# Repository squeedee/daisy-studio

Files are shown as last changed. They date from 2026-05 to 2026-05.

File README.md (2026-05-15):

# Daisy Studio - [Website](https://squeedee.github.io/daisy-studio/)

| Front | Back |
|---|---|
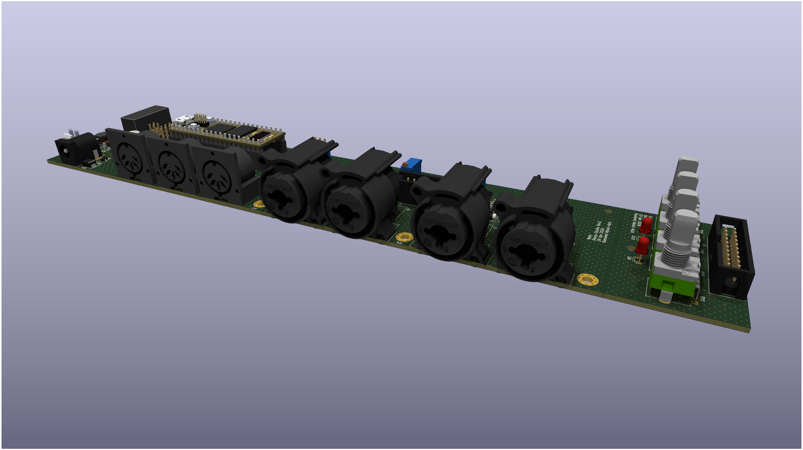
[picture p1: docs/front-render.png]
Front render
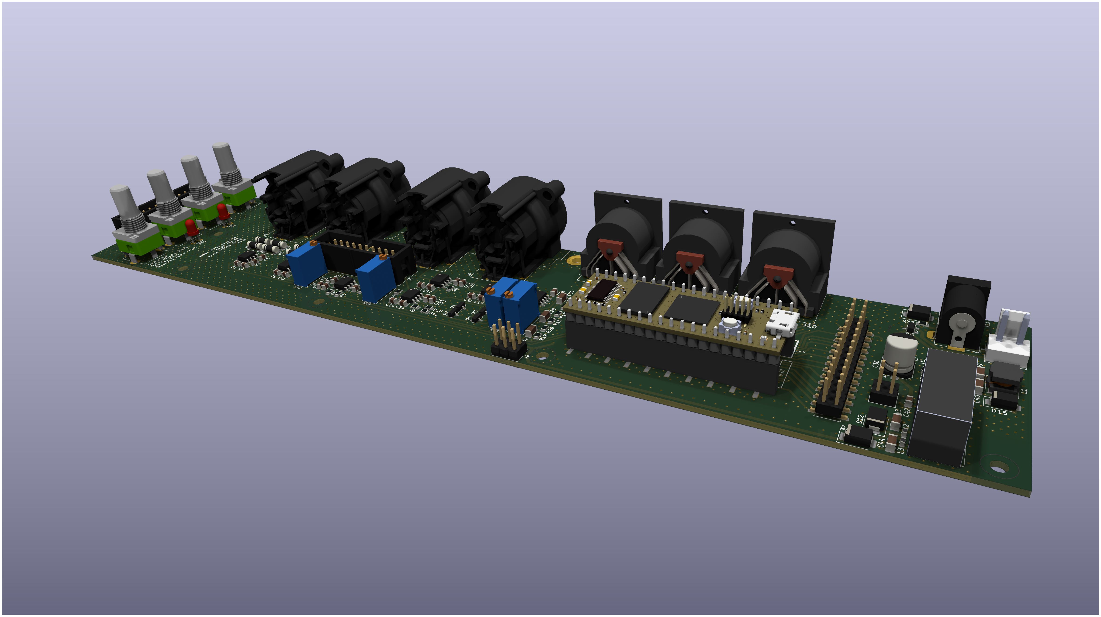
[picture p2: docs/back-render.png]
Back render
|  |  |

A development board for the [Electrosmith Daisy Seed](https://www.electro-smith.com/daisy/daisy)
DSP module, providing professional studio-grade balanced line input and output.

Schematic PDF: [docs/Daisy Studio Rev2.pdf](docs/Daisy%20Studio%20Rev2.pdf)

THD measurement report (Board 1, loopback, post-F9 retrim — ≤ −88 dB / ≤ 0.004 % @ 1 kHz):
[docs/Daisy THD Meter.pdf](docs/Daisy%20THD%20Meter.pdf)

The board is designed as a **flexible development board** to prototype designs
for:

* synthesizers, desktop, rackmount or with keybeds.
* effects modules, desktop or rackmount.

The main PCB carries all active circuitry and connects to a passive **daughterboard**
that holds the user-facing controls (level pots, clip LEDs).

The designer can replace the daughterboard with controls connected however they desire.

## Features

- **Balanced audio I/O** using THAT Corporation ICs:
    - 2× THAT1246 balanced line receivers (stereo input).
    - 2× THAT1646 balanced line drivers (stereo output).
- **OPA1656 gain stages** on input and output, calibrated for +24 dBu
  peak studio levels.
- **BJT input clamp** with an LM2903 comparator clip indicator —
  protects the Seed's PCM3060 ADC against overdrive and provides user's with professional gain stage control.
- **Neutrik combo jacks** (NCJ6FA-H-0) on all four audio connectors —
  accept both XLR and 1/4" TRS
- **MIDI** in, out, and thru via 5-pin DIN connectors with optoisolated input.
- **Micro SD card** slot.
- **Daughterboard header** (2×10 IDC, ribbon or stack-mount) for
  user-facing gain controls and input clip LEDs.
- **Seed GPIO breakout** header (2×14) for user expansion
- **Analog power** header (2x3) provides +-12v rails for additional analog circuits.
- **Panel power switch** header (JST VH) — ships with a shunt by default,
  swap for a switch harness when wanted.
- **Isolated Chassis Ground** jumper JP1 allows chassis ground to be kept separate 
  from signal grounds. Mounting posts (H1, H4 and H7) share the chassis ground/shield 
  of the Neutrik connectors.

## Circuit Function

### Audio Input

```
Balanced in → THAT1246 → OPA1656 (fixed gain) → daughterboard pot
                                                       ↓
   Daisy Seed ← C_aa anti-alias ← BJT clamp ← R_out (3.3 kΩ) ←
```

The **THAT1246** balanced receiver converts the differential XLR input
to single-ended at −6 dB, keeping +24 dBu peaks within the ±10 V output
swing of the ±12 V rails. Its **Sense pin (5)** is brought back as a
separate trace to the OPA1656 inverting node — Kelvin-connected past
the input resistor — so the THAT1246's internal feedback amp absorbs
any voltage drop across `R_in`, eliminating it as a gain-error term.

The **OPA1656** runs as an inverting amplifier at a **fixed gain of
1.2×** (R_fb = 12 kΩ, R_in = 10 kΩ). At +24 dBu peak input the op-amp
output reaches ±10.45 V, ~550 mV from the ±11 V clip rails. Fixed gain
(rather than a pot in the feedback path) keeps loop phase margin
constant across user level adjustments, and the high-impedance summing
junction stays entirely on the main PCB.

User level is set by a **10 kΩ log pot on the daughterboard**, wired
as a passive three-terminal voltage divider downstream of the op-amp.
Both header legs are low-impedance: the op-amp drives the CW terminal,
and the pot wiper returns to the main PCB into `R_out` (3.3 kΩ) which
caps fault current into the clamp under pathological overdrive.

The **BJT clamp** is the design's centrepiece. A complementary pair
(2N3906 PNP + 2N3904 NPN) per channel clamps the Seed input pin against
±1.565 V references derived from the ±12 V rails by 10 kΩ / 1.5 kΩ
dividers and held stiff at audio frequencies by 47 µF MLCCs. The
transistors' β ≈ 200 means only Ic / β flows through the reference
divider base connection, so the references stay nearly stationary even
under sustained overdrive — the "reference pumping" failure mode that
limits passive diode clamps. The sharp emitter-base knee (NF ≈ 1.24,
versus ~1.82 for diodes) lets the clean signal use the full ADC range
with no distortion. Simulations across five tolerance corners shows
worst-case codec voltage of 4.64 V under +24 dBu pathological overdrive
— 164 mV margin to the PCM3060's 4.8 V damage ceiling.

A **1 nF C0G capacitor** at the Seed input pin, after the clamp, forms
a single-pole LPF with `R_out` plus the pot wiper source impedance.
The corner stays between 27 kHz (pot mid) and 48 kHz (pot ends), well
above the audio band, attenuating wideband op-amp noise and out-of-band
content before it reaches the PCM3060's sigma-delta ADC.

A **clip indicator** uses an LM2903 comparator monitoring the Seed
input against an adjustable threshold. A trim pot on the daughterboard
(0 V to +1.565 V) sets the threshold; the open-collector output sinks
an LED current path against +12 V through a 1 kΩ limit on the main PCB.
At audio frequencies the LED flickers faster than the eye sees — a dim
glow at light clipping, bright at heavy. A single LM2903 covers both
channels.

### MIDI

Standard MIDI 1.0 — a 5 mA current loop at 31.25 kbaud on three
SDS-50J DIN-5 jacks (IN, OUT, THRU).

```
DIN-5 IN ── 220R × 2 ── 1N4148W ── H11L1SM (opto, Schmitt)
                                       ├── 270R pull-up to +3V3D
                                       ├── → MIDI_RX → Seed UART RX
                                       └── 33R × 2 → DIN-5 THRU

Seed UART TX ── MIDI_TX ── 33R + 10R ── DIN-5 OUT
```

The H11L1SM Schmitt-trigger optocoupler galvanically isolates the input
per the MIDI 1.0 electrical spec and presents clean UART edges to the
Seed. THRU buffers the same opto output through a second pair of 33 Ω
series resistors. OUT is driven directly from the Seed UART TX through
a 33 Ω + 10 Ω series pair.

### Audio Output

```
Seed audio → OPA1656 (gain ~9.1×, C_fb LPF) → daughterboard pot
                                                       ↓
        XLR ← SM4004 phantom clamps ← THAT1646 balanced driver ←
```

The Seed's PCM3060 outputs ~2 V p-p at digital full scale (~−1 dBu
single-ended, ~+5 dBu differential through the THAT1646 alone). An
OPA1656 inverting gain stage closes the ~20 dB gap to the +24 dBu
studio peak target. R_in is a fixed 2.2 kΩ; R_fb is **15 kΩ fixed in
series with a 10 kΩ multi-turn cermet trimmer** (e.g. Bourns
3296W-1-103). Mid-trim lands at gain ~9.1× (+23.7 dBu peak); the
25-turn trim resolves to ~0.5% of R_fb. The fixed floor prevents
accidental hard clipping if the wiper loses contact, and the ceiling
(R_fb ≤ 25 kΩ) stays below the OPA1656's onset of clipping.

A **100 pF C0G across R_fb** turns the gain stage into a single-pole
LPF with f_c ≈ 80 kHz at nominal trim. The Seed Rev 7's PCM3060 has
out-of-band delta-sigma noise that the codec's internal RC alone does
not adequately attenuate; the in-feedback-loop LPF handles this
without adding any series parts. C0G dielectric is required —
X5R/X7R have voltage-coefficient distortion that would intrude into
the audio band when the cap is in the feedback path. Sim shows
−0.27 dB at 20 kHz, −22 dB at 1 MHz.

User output level is a **10 kΩ log pot per channel on the
daughterboard**, voltage-divider-wired downstream of the op-amp. Two
separate pots (not ganged) let users pick their own taper or matching
strategy. The THAT1646's high-Z input means the op-amp sees a constant
10 kΩ load regardless of wiper position.

The **THAT1646** balanced driver converts the single-ended pot wiper
back to a differential XLR pair. Sense pins close the feedback loop at
the XLR connector for cross-coupled output impedance and immunity to
load imbalance.

**Phantom-power protection**: four SM4004 diodes per channel (two per
XLR pin) clamp the THAT1646 output to the ±12 V rails. If an XLR is
plugged into a phantom-enabled mic preamp, +48 V through the preamp's
6.8 kΩ feed produces ~5 mA per pin into the clamp — well within the
SM4004's 1 A rating.

**Rail protection** (phantom back-feed when the gear is powered off):
one SMBJ15CA bidirectional TVS on each ±12 V rail to AGND, placed near
the RS3-1212D output. Same part as the input over-voltage TVS for BOM
consolidation. Clamps when the rail magnitude exceeds ~16 V.

### Daughterboard Architecture

The main PCB commits to a **2×10 (20-pin) 2.54 mm pitch through-hole
footprint** for the daughterboard header. Daughterboard PCBs are
**fully passive**, populating only:

- 2× input level pots (10 kΩ log)
- 2× output level pots (10 kΩ log)
- 2× clip LEDs

No ICs, no power rails, and no high-impedance feedback nodes cross the
header — shorting any two daughterboard signals together cannot damage
the main PCB. The 18 needed signal pins fit in the 20-pin footprint
with two AGND pins at the bottom; AGND is interleaved on every audio
pair.

The same footprint supports two build modes:

- **Cable-mount**: a shrouded IDC header (e.g. Samtec
  TSS-110-01-G-D) on the main PCB, 20-way IDC ribbon to a matching
  socket, or a soldered header (lower profile) on the daughterboard.
  Cable length ≤ 150 mm comfortable.
- **Pins and Shielded pairs**: Alternatively pins and shielded wire pairs
  can run longer distances.
- **Stack-mount (default)**: Samtec flex-stacking posts; the daughterboard sits
  directly above the main PCB at a chosen height, no cable.

Pinout (canonical):

| Pin | Signal | Pin | Signal |
|----:|---|----:|---|
| 1 | AGND | 2 | AGND |
| 3 | IN_OPA_L | 4 | IN_OPA_R |
| 5 | IN_WIPER_L | 6 | IN_WIPER_R |
| 7 | AGND | 8 | AGND |
| 9 | OUT_OPA_L |  10 | OUT_OPA_R |
|  11 | OUT_WIPER_L  |  12 | OUT_WIPER_R  |
|  13 | AGND |  14 | AGND |
|  15 | CLIP_LED_A_L |  16 | CLIP_LED_A_R |
|  17 | CLIP_LED_K_L |  18 | CLIP_LED_K_R |
|  19 | AGND |  20 | AGND |

The moderate-Z `IN_WIPER_*` pair and the fast-edge `CLIP_LED_K_*` pair
(LM2903 open-collector) sit at opposite ends of the header to limit
capacitive crosstalk on a ribbon. User extensions that need active
circuitry use the GPIO breakout header instead.

### Seed GPIO Breakout

A **2×14 (28-pin) 2.54 mm vertical pin header** brings out every Seed
GPIO not committed to the on-board audio (ADC/DAC), MIDI (UART_RX/TX),
or USB (D+/D−, VBUS) — plus +5 V, +3V3D, and DGND for downstream
circuits. Pin-to-net assignment is slightly illogical, as they were selected
to minimise via count and trace crossings between the Seed and the
breakout.

Analog ±12 V rails are not on the breakout (or on the daughterboard
header); they distribute through the dedicated power header.

### Power

```
12 V barrel jack → SW1 (panel switch / shunt) → DMP3056L (rev-polarity)
                                                       ↓
                                              SMBJ15CA TVS (overvoltage)
                                                       ↓
                                                100 µF bulk → +12V_RAW
                                                       ├─→ TPS54302 → +5V
                                                       └─→ RS3-1212D → ±12V
```

A 12 V wall-wart feeds a 2.1 mm barrel jack. **SW1** — a JST B2P-VH
2-pin THT header in series after the jack — takes either a pre-crimped
shunt harness (default, bypasses the switch) or an external panel
switch harness (VHR-2N housing, SVH-21T-P1.1 contacts). Placing the
switch *before* reverse-polarity protection means rev-pol and TVS
clamping still function during a miswired wall-wart event regardless
of switch state.

Reverse polarity is blocked by a **DMP3056L-13** P-FET (VGS_max ±20 V,
RDS_on ~51 mΩ) — sized for the −12 V on the gate that this
configuration imposes when input is correct. An **SMBJ15CA**
bidirectional TVS clamps any over-voltage spike from a misbehaved
supply. A 100 µF / 25 V electrolytic provides bulk on +12V_RAW.

The **TPS54302 buck** (SOT-23-6) generates +5 V from +12V_RAW for the
Daisy Seed and the MIDI front-end. Feedback divider 100 kΩ / 13.3 kΩ
sets Vout ≈ 5.07 V; inductor L3 = 10 µH (Bourns SRN6045TA). Output
caps are 2× 22 µF / 25 V X7R 1206 (5× voltage derating). A dedicated
**10 µF / 25 V X7R 1206** input MLCC sits at the VIN pin to handle the
buck's pulsed input current at 500 kHz with low loop inductance — the
part the TPS54302 datasheet calls for. A defensive **SMAJ5.0A** TVS
clamps +5 V to GND near the Seed.

The **Recom RS3-1212D** isolated DC/DC (SIP-8, 3 W, regulated ±2%,
±125 mA per rail) generates the ±12 V analog rails. The output passes
through 2× BLM18PG121SN1 ferrite beads into the rest of the board.

Power budget (±12 V rails):

| Consumer | +12V mA | −12V mA |
|---|---:|---:|
| 2× THAT1246 (input receivers)  | 16.0 | 16.0 |
| 2× THAT1646 (output drivers) | 18.0 | 18.0 |
| 1× OPA1656 (input gain, dual)  | 7.8 | 7.8 |
| 1× OPA1656 (output gain, dual) | 7.8 | 7.8 |
| BJT clamp reference dividers | 2.1 | 2.1 |
| LM2903 quiescent | 0.5 | 0.5 |
| **Total** | **~52** | **~52** |

≈ 1.25 W output power against the RS3-1212D's 3 W rating — ~2.4×
headroom, defensive margin against component tolerance and operating
temperature; margin for user consumption on the power header will be
validated and provided as a spec (once the boards are tested)

**Grounding**: AGND and DGND meet near the Seed's pin 20 (AGND) in a two
layer connection between AGND and DGND isolated planes.

AGND and CHASSIS meet only at JP1 (a solder jumper on the underside of the board)
Users can isolate the chassis ground of the Neutrik connectors by cutting this
jumper. Chassis Ground connects to all three mounting holes left, center and right
of the Neutrik connectors.

## Project Structure

Designed in KiCad 8 with a hierarchical schematic:

- `daisy-studio.kicad_sch` — root sheet
- `audio_input.kicad_sch` — input section (THAT1246, OPA1656, BJT clamp, LM2903)
- `audio_output.kicad_sch` — output section (OPA1656, THAT1646, phantom protection)
- `daisy_seed.kicad_sch` — Seed module + MIDI front-end + GPIO breakout
- `power.kicad_sch` — power section (buck + isolated DC/DC + protection)
- `daughter.kicad_sch` — passive daughterboard (separate fab)
- `misc.kicad_sch` — daughterboard header and mounting parts for the main board.

LTspice simulations validating the input-stage clamp / signal path and
the output reconstruction LPF live under `sim/input/` and `sim/output/`.

## Status

Rev 2 — fab sent.

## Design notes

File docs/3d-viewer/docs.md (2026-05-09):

# Daisy Studio (Rev2b)

[[view:overview|Front View]] and [[view:back|Back View]]

Development board for the Electrosmith Daisy Seed that brings a slew of features

## Clean Power [[view:power|Power]]

* 5V for the Seed and your UX via the TPS54302 buck (U10).
* Clean **±12V dual** rails for the analog stages from an RS3-1212D isolated DC/DC.
* Overvoltage protection on every rail via SMBJ15CA TVS, which also capture backfeed from voltage sources on the outputs
  when power is not applied.
* Reverse-polarity protection with a DMP3056L-13 P-FET.
* Optional power switch header at SW1 (can be jumpered).

## Power Headers [[view:power-header|Power Headers]]

* 5V and 3.3V at J12.
* ±12V at J8

## Balanced Audio In [[view:audio-input|Balanced Input]]

- Studio level (+24 dBu peak), balanced input on Neutrik Combo Jacks (J4, J6) via THAT1246 differential receivers.
- Gain control and clip indicators for perfect gain staging.
- Clip-threshold trim (RV7, RV8) so the clip LED lights *before* the protection clamp engages.
- BJT clamp (2N3904 + 2N3906 pairs at Q1, Q4 / Q2, Q3) protects the Seed's PCM3060 ADC from overdrive — sharp transistor
  knee, no diode-clamp distortion bleeding into your signal.
- C0G anti-alias cap (C16, C24) on each Seed input pin attenuates out-of-band noise before the codec's sigma-delta ADC
  sees it.

## Balanced Audio Out [[view:audio-output|Balanced Output]]

- Studio level (+24 dBu peak) on Neutrik Combo Jacks (J1, J2) via THAT1646 line drivers.
- Per-channel volume pots on the daughterboard so each output trims independently.
- Output gain trimmed once at calibration with 25-turn cermet pots (RV2, RV4) on the OPA1656 gain stage (U3).
- Phantom-power-safe: SM4004 diode clamps (D1–D8) to the ±12V rails on every XLR pin.

## 5-Pin MIDI [[view:midi|MIDI]]

- IN (J10), OUT (J9), and THRU (J7) on DIN-5 jacks.
- Galvanically isolated input via the H11L1SM Schmitt-trigger optocoupler (U8) — clean UART edges to the Seed.
- Standard MIDI 1.0 electrical spec.

## Seed [[view:seed|Seed]]

- Socketed Daisy Seed Rev 7 at U9.
- Every Seed GPIO not committed to onboard audio, MIDI, or USB is on the **2×14 GPIO breakout** at J11, plus +5V, +3V3D
  and DGND for your circuits.
- MicroSD slot (J14, underside of board) wired to the Seed's SD interface.
- USB and audio I/O routed straight through, no muxing.

## Daughter Board [[view:daughter-header|Daughter Board]]

- **2×10 (20-pin) 0.1" header** at J3 — your daughterboard, your UX layout.
- Fully passive: input/output pots + clip LEDs only. No ICs cross the header.
- Stack-mount or IDC ribbon — pick whichever fits your enclosure.
- AGND interleaved on every audio pair, so shorting any two pins won't damage the main PCB.

---

<p style="color: var(--muted); font-size: 12px;">
Source: <code>daisy-studio.kicad_pcb</code> · GLB exported with
<code>kicad-cli pcb export glb</code> · Viewer:
<a href="https://modelviewer.dev/" target="_blank" rel="noopener">&lt;model-viewer&gt;</a>
</p>

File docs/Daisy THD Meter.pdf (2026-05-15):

## Daisy THD Meter Report

5/15/2026, 6:31:22 PM

SETTINGS

Mode | Loopback
Channel | R
Window | Coherent (no window)
Test frequency | 1007.8125 Hz (bin 86)
FFT size / fs | 4096 / 48 kHz (bin width 11.71875 Hz)
Drive amplitude | 1.0000

MEASUREMENT

Fundamental | -4.02 dBFS
THD | -89.01 dB (0.0035 %)
THD + N | -89.01 dB
Peak | -4.0 dBFShold -4.0
Noise floor | -124.79 dBFS
5/15/26, 6:31 PM | Daisy THD Meter
localhost:63342/daisy-studio/firmware/projects/thd-meter/thd-meter.html?_ijt=5og25p2hi8ko8jm5ajpe94mvsb&_ij_reload=RELOAD_ON_SAVE | 1/2

HARMONICS (DB BELOW FUNDAMENTAL)

Order | dB | Visual

2

nd | -95.3

3

rd | -91.4

4

th | -99.7

5

th | -99.6

6

th | -112.0

7

th | -118.3

8

th | -122.5

9

th | -116.2

THD HISTORY (SNAPSHOT)

NOTES

—

localhost:63342/daisy-studio/firmware/projects/thd-meter/thd-meter.html?_ijt=5og25p2hi8ko8jm5ajpe94mvsb&_ij_reload=RELOAD_ON_SAVE | 2/2

## Daisy THD Meter Report

5/15/2026, 6:31:36 PM

SETTINGS

Mode | Loopback
Channel | L
Window | Coherent (no window)
Test frequency | 1007.8125 Hz (bin 86)
FFT size / fs | 4096 / 48 kHz (bin width 11.71875 Hz)
Drive amplitude | 1.0000

MEASUREMENT

Fundamental | -3.51 dBFS
THD | -87.93 dB (0.0040 %)
THD + N | -87.93 dB
Peak | -3.5 dBFShold -3.5
Noise floor | -125.57 dBFS
localhost:63342/daisy-studio/firmware/projects/thd-meter/thd-meter.html?_ijt=5og25p2hi8ko8jm5ajpe94mvsb&_ij_reload=RELOAD_ON_SAVE | 1/2

HARMONICS (DB BELOW FUNDAMENTAL)

Order | dB | Visual

2

nd | -88.9

3

rd | -95.5

4

th | -113.0

5

th | -105.2

6

th | -128.0

7

th | -121.9

8

th | -117.5

9

th | -115.2

THD HISTORY (SNAPSHOT)

NOTES

—

localhost:63342/daisy-studio/firmware/projects/thd-meter/thd-meter.html?_ijt=5og25p2hi8ko8jm5ajpe94mvsb&_ij_reload=RELOAD_ON_SAVE | 2/2

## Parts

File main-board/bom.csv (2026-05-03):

Refs | Value | Footprint | Manufacturer | MPN | Mouser P/N | Datasheet | Link | Description
C1,C2,C5,C6,C10,C13,C14,C17,C19,C20,C23,C25,C26,C31,C35,C37,C42 | 100n | Capacitor_SMD:C_0805_2012Metric | Samsung Electro-Mechanics | CL21B104KBCNNNC | 187-CL21B104KBCNNNC | https://www.mouser.com/datasheet/2/585/MLCC-1837944.pdf | https://www.mouser.com/ProductDetail/Samsung-Electro-Mechanics/CL21B104KBCNNNC?qs=349EhDEZ59pEfpnm5yBEmQ%3D%3D | Unpolarized capacitor
C3,C4,C7,C11,C12,C18,C21,C28 | 10u | Capacitor_SMD:C_0805_2012Metric | Samsung Electro-Mechanics | CL21A106KAYNNNE | 187-CL21A106KAYNNNE | https://www.mouser.com/datasheet/2/585/MLCC-1837944.pdf | https://www.mouser.com/ProductDetail/Samsung-Electro-Mechanics/CL21A106KAYNNNE?qs=yOVawPpwOwmTXAd4dJtNjA%3D%3D | Unpolarized capacitor
C8,C15 | 100p C0G | Capacitor_SMD:C_0805_2012Metric | Yageo | CC0805JRNPO9BN101 | 603-CC805JRNPO9BN101 | ~ | https://www.mouser.com/ProductDetail/YAGEO/CC0805JRNPO9BN101?qs=AgBp2OyFlx%252BIBvbseB%252BJ9Q%3D%3D | Unpolarized capacitor
C9,C16,C22,C24 | 1n | Capacitor_SMD:C_0805_2012Metric | Samsung Electro-Mechanics | CL21B102KBCNNNC | 187-CL21B102KBCNNNC | ~ | https://www.mouser.com/ProductDetail/Samsung-Electro-Mechanics/CL21B102KBCNNNC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 | Unpolarized capacitor
C27,C29,C30,C32 | 47u | Capacitor_SMD:C_1206_3216Metric | Samsung Electro-Mechanics | CL31A476MQHNNNE | 187-CL31A476MQHNNNE | ~ | https://www.mouser.com/ProductDetail/Samsung-Electro-Mechanics/CL31A476MQHNNNE?qs=349EhDEZ59oTPuXhtXd6IQ%3D%3D | Unpolarized capacitor
C33,C34 | 1n C0G | Capacitor_SMD:C_0603_1608Metric | Yageo | CC0603JRNPO8BN102 | 603-CC603JRNPO8BN102 | ~ | https://www.mouser.com/ProductDetail/YAGEO/CC0603JRNPO8BN102?qs=AgBp2OyFlx%2F%252ByYeYqr8Gwg%3D%3D | Unpolarized capacitor
C36 | 100u 25V | Capacitor_SMD:CP_Elec_6.3x7.7 | Panasonic | EEE-FK1E101XP | 667-EEE-FK1E101XP | https://industrial.panasonic.com/cdbs/www-data/pdf/RDE0000/ABA0000C1181.pdf | https://www.mouser.com/ProductDetail/Panasonic/EEE-FK1E101XP?qs=qE6bgDGEOCsW6NVslB4juQ%3D%3D | Polarized capacitor
C38 | 75pF | Capacitor_SMD:C_0805_2012Metric | Yageo | CC0805JRNPO9BN750 | 603-CC805JRNPO9BN750 | https://www.mouser.com/datasheet/3/508/1/upy-np0x7r_mv_100-to-630v.pdf | https://www.mouser.com/ProductDetail/YAGEO/CC0805JRNPO9BN750?qs=57cj7OiSijnuUmSjyzaxjQ%3D%3D | Unpolarized capacitor
C39 | 10u 25V | Capacitor_SMD:C_1206_3216Metric | Samsung Electro-Mechanics | CL31A106KAHNNNE | 187-CL31A106KAHNNNE | ~ | https://www.mouser.com/ProductDetail/Samsung-Electro-Mechanics/CL31A106KAHNNNE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 | Unpolarized capacitor
C40,C41,C43,C44 | 22u 25V | Capacitor_SMD:C_1206_3216Metric | Samsung Electro-Mechanics | CL31A226MAHNNNE | 187-CL31A226MAHNNNE | ~ | https://www.mouser.com/ProductDetail/Samsung-Electro-Mechanics/CL31A226MAHNNNE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 | Unpolarized capacitor
D1-D8 | SM4004 | Diode_SMD:D_MELF | Rectron | SM4004-W | 583-SM4004 | http://cdn-reichelt.de/documents/datenblatt/A400/SMD1N400%23DIO.pdf | https://www.mouser.com/ProductDetail/Rectron/SM4004-W?qs=Iw9Ubr57Px1JditZNV5Q2Q%3D%3D | 400V 1A General Purpose Rectifier Diode, MELF
D9,D10 | LED | LED_THT:LED_D3.0mm | Kingbright | WP710A10ID | 604-WP710A10ID | ~ | https://www.mouser.com/ProductDetail/Kingbright/WP710A10ID?qs=wRBQ8ZgBZ98VyHeNIlWGkQ%3D%3D | Light emitting diode
D11 | 1N4148WS | Diode_SMD:D_SOD-323 | Diodes Incorporated | 1N4148WS-7-F | 621-1N4148WS-F | https://www.vishay.com/docs/85751/1n4148ws.pdf | https://www.mouser.com/ProductDetail/Diodes-Incorporated/1N4148WS-7-F?qs=4drIV0IxA0r8aNy7%2Fu4kVw%3D%3D | 75V 0.15A Fast switching Diode, SOD-323
D12-D14 | SMBJ15CA | Diode_SMD:D_SMB | Diodes Incorporated | SMBJ15CA-13-F | 621-SMBJ15CA-13-F | ~ | https://www.mouser.com/ProductDetail/Diodes-Incorporated/SMBJ15CA-13-F?qs=gaDBXWSqsDDjKf8DgzD9yw%3D%3D | Bidirectional transient-voltage-suppression diode
D15 | SMAJ5.0A | Diode_SMD:D_SMA | Diodes Incorporated | SMAJ5.0A-13-F | 621-SMAJ5.0A-13-F | https://www.littelfuse.com/media?itemid=75e32973-b177-4ee3-a0ff-cedaf1abdb93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 | https://www.mouser.com/ProductDetail/Diodes-Incorporated/SMAJ5.0A-13-F?qs=gaDBXWSqsDCr%2F5d1gQdliw%3D%3D | 400W unidirectional Transient Voltage Suppressor, 5.0Vr, SMA(DO-214AC)
J1,J2,J4,J6 | NCJ6FA-H-0 | Connector_Audio:Jack_XLR-6.35mm_Neutrik_NCJ6FA-H-0_Horizontal | Neutrik | NCJ6FA-H-0 | 568-NCJ6FA-H-0 | https://www.neutrik.com/en/product/ncj6fa-h-0 | https://www.mouser.com/ProductDetail/Neutrik/NCJ6FA-H-0?qs=aEaV1LakhLaCrLXco%252BtEjw%3D%3D | Combo A series, 3 pole XLR female receptacle with 6.35mm (1/4in) stereo jack, horizontal PCB mount, retention spring
J3,J5 | Conn_02x10_Odd_Even | Connector_IDC:IDC-Header_2x10_P2.54mm_Vertical | Preci-dip | 892-70-020-10-001101 | 437-8927002010001101 | ~ | https://www.mouser.com/ProductDetail/Preci-dip/892-70-020-10-001101?qs=jrVTBkKbt4YjW5Ssdpp6%252BA%3D%3D | Generic connector, double row, 02x10, odd/even pin numbering scheme (row 1 odd numbers, row 2 even numbers), script generated (kicad-library-utils/schlib/autogen/connector/)
J7,J9,J10 | SDS-50J | daisy-studio:SDS50J | Same Sky | SDS-50J | 490-SDS-50J | https://www.mouser.com/datasheet/3/6118/1/sds-j.pdf | https://www.mouser.com/ProductDetail/Same-Sky/SDS-50J?qs=WyjlAZoYn50GAH9uA%252BxiOw%3D%3D | 5 Pin, Right-Angle Receptacle, 180
J8 | Conn_02x03 | Connector_PinHeader_2.54mm:PinHeader_2x03_P2.54mm_Vertical | Wurth Elektronik | 61300621121 | 710-61300621121 | https://www.we-online.com/components/products/datasheet/61300621121.pdf | https://www.mouser.com/ProductDetail/Wurth-Elektronik/61300621121?qs=PhR8RmCirEbASZ60vyqaXQ%3D%3D | 2x3 Pin Header 2.54mm — generic, suggested unverified (similar family to rev1 J1 Wurth header)
J11 | Conn_02x14_Odd_Even | Connector_PinHeader_2.54mm:PinHeader_2x14_P2.54mm_Vertical_SMD | Samtec | TSM-114-01-L-DV-A | 200-TSM11401LDVA | ~ | https://www.mouser.com/ProductDetail/Samtec/TSM-114-01-L-DV-A?qs=FESYatJ8odJReZLbMKEV%2FA%3D%3D | Generic connector, double row, 02x14, odd/even pin numbering scheme (row 1 odd numbers, row 2 even numbers), script generated (kicad-library-utils/schlib/autogen/connector/)
J12 | Conn_02x02_Odd_Even | Connector_PinHeader_2.54mm:PinHeader_2x02_P2.54mm_Vertical | Amphenol | 10129381-904003BLF | 649-1012938190403BLF | ~ | https://www.mouser.com/ProductDetail/Amphenol-FCI/10129381-904003BLF?qs=0lQeLiL1qyY7Xp84ndpsoA%3D%3D | Generic connector, single row, 01x04, script generated
J13 | Barrel_Jack_MountingPin | Connector_BarrelJack:BarrelJack_Horizontal | Same Sky (CUI) | PJ-002AH | 490-PJ-002AH | ~ | https://www.mouser.com/ProductDetail/Same-Sky/PJ-002AH?qs=WyjlAZoYn53W8%2FAJwYIf7Q%3D%3D | DC Barrel Jack with a mounting pin
J14 | Micro_SD_Card_Det2 | Connector_Card:microSD_HC_Hirose_DM3BT-DSF-PEJS | Hirose | DM3BT-DSF-PEJS | 798-DM3BT-DSF-PEJS | https://www.hirose.com/en/product/document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 | https://www.mouser.com/ProductDetail/Hirose-Connector/DM3BT-DSF-PEJS?qs=nSryOFbzj8LLRwoFXPa7yA%3D%3D | Micro SD Card Socket with two card detection pins
L1 | 10uH | Inductor_SMD:L_Bourns_SRN6045TA | Bourns | SRN6045TA-100M | 652-SRN6045TA-100M | https://www.mouser.com/datasheet/3/40/1/srn6045ta.pdf | https://www.mouser.com/ProductDetail/Bourns/SRN6045TA-100M?qs=Vt59ZOdFuWZBf9gWI0WHQg%3D%3D | Inductor
L2,L3 | BLM18PG121SN1 | Inductor_SMD:L_0603_1608Metric | Murata | BLM18PG121SN1D | 81-BLM18PG121SN1D | https://www.mouser.com/datasheet/3/76/1/ENFA0003.pdf | https://www.mouser.com/ProductDetail/Murata-Electronics/BLM18PG121SN1D?qs=tY8e8KZalarVxhnmnUYZ1A%3D%3D | Inductor
PS1 | RS3-1212D | daisy-studio:TMR1210 | RECOM | RS3-1212D | 919-RS3-1212D | https://tracopower.com/tmr3e-datasheet/ | https://www.mouser.com/ProductDetail/RECOM-Power/RS3-1212D?qs=8OBu2JtKQqqOnuIVdj%2FAVQ%3D%3D | 3 Watt DC/DC converter, industrial, 2:1 input, regulated, 1600 VDC I/O-isolation, encapsulated, SIP-8
Q1,Q4 | MMBT3904 | Package_TO_SOT_SMD:SOT-23 | Onsemi | MMBT3904LT1G | 863-MMBT3904LT1G | https://www.onsemi.com/pub/Collateral/2N3903-D.PDF | https://www.mouser.com/ProductDetail/onsemi/MMBT3904LT1G?qs=HVbQlW5zcXUYZ2Fy0YF3FQ%3D%3D | 0.2A Ic, 40V Vce, Small Signal NPN Transistor, TO-92
Q2,Q3 | MMBT3906 | Package_TO_SOT_SMD:SOT-23 | Onsemi | MMBT3906LT1G | 863-MMBT3906LT1G | https://www.onsemi.com/pub/Collateral/2N3906-D.PDF | https://www.mouser.com/ProductDetail/onsemi/MMBT3906LT1G?qs=HVbQlW5zcXXO9RcjXx8aQw%3D%3D | -0.2A Ic, -40V Vce, Small Signal PNP Transistor, TO-92
Q5 | DMP3056L-13 | Package_TO_SOT_SMD:SOT-23-3 | Diodes Incorporated | DMP3056L-13 | 621-DMP3056L-13 | https://4donline.ihs.com/images/VipMasterIC/IC/DIOD/DIOD-S-A0012884531/DIOD-S-A0012915142-1.pdf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 | https://www.mouser.com/ProductDetail/Diodes-Incorporated/DMP3056L-13?qs=OVC8WVYZliRFsnMzvbeoig%3D%3D | DMP3056L-13
R1,R3 | 1k | Resistor_SMD:R_0805_2012Metric | Yageo | RC0805FR-071KL | 603-RC0805FR-071KL | ~ | https://www.mouser.com/ProductDetail/YAGEO/RC0805FR-071KL?qs=1ogmaHw32WJjeGY0DHXakQ%3D%3D | Resistor
R2,R7 | 15k | Resistor_SMD:R_0805_2012Metric | Yageo | RC0805FR-0715KL | 603-RC0805FR-0715KL | ~ | https://www.mouser.com/ProductDetail/YAGEO/RC0805FR-0715KL?qs=8Y8p%252BasKcI4opTh4HnCDuA%3D%3D | Resistor
R4,R9 | 12k 1% | Resistor_SMD:R_0805_2012Metric | Yageo | RC0805FR-0712KL | 603-RC0805FR-0712KL | ~ | https://www.mouser.com/ProductDetail/YAGEO/RC0805FR-0712KL?qs=9zxuD9RB%2FCVgoQMklW9lMg%3D%3D | Resistor
R5,R6 | 2k2 1% | Resistor_SMD:R_0805_2012Metric | Yageo | RC0805FR-072K2L | 603-RC0805FR-072K2L | ~ | https://www.mouser.com/ProductDetail/YAGEO/RC0805FR-072K2L?qs=CSLd874fYV2eT6iKTza3nw%3D%3D | Resistor
R8,R16,R33 | 10k | Resistor_SMD:R_0805_2012Metric | Yageo | RC0805FR-0710KL | 603-RC0805FR-0710KL | https://www.mouser.com/catalog/specsheets/YAGEO_PYu_RC_Group_51_RoHS_L_12.pdf | https://www.mouser.com/ProductDetail/YAGEO/RC0805FR-0710KL?qs=7bY8808IzHq6vrU3BeiiYw%3D%3D | Resistor
R10,R11 | 3.3k 1% | Resistor_SMD:R_0805_2012Metric | Yageo | RC0805FR-0713K3L | 603-RC0805FR-0713K3L | https://www.mouser.com/datasheet/2/447/PYu_RC_Group_51_RoHS_L_11-1984063.pdf | https://www.mouser.com/ProductDetail/YAGEO/RC0805FR-0713K3L?qs=7bY8808IzHqrbhVfypq6iw%3D%3D | Resistor
R12,R14,R15,R19 | 1.5k 1% | Resistor_SMD:R_0805_2012Metric | Yageo | RC0805FR-071K5L | 603-RC0805FR-071K5L | ~ | https://www.mouser.com/ProductDetail/YAGEO/RC0805FR-071K5L?qs=8Y8p%252BasKcI6LbaohOVk4HA%3D%3D | Resistor
R13,R17,R18,R20 | 10k 1% | Resistor_SMD:R_0805_2012Metric | Yageo | RC0805FR-0710KL | 603-RC0805FR-0710KL | https://www.mouser.com/catalog/specsheets/YAGEO_PYu_RC_Group_51_RoHS_L_12.pdf | https://www.mouser.com/ProductDetail/YAGEO/RC0805FR-0710KL?qs=7bY8808IzHq6vrU3BeiiYw%3D%3D | Resistor
R21-R23 | 33R | Resistor_SMD:R_0805_2012Metric | Yageo | RC0805FR-0733RL | 603-RC0805FR-0733RL | https://www.mouser.com/catalog/specsheets/YAGEO_PYu_RC_Group_51_RoHS_L_12.pdf | https://www.mouser.com/ProductDetail/YAGEO/RC0805FR-0733RL?qs=g6xwsc4j%252B%2Fq7KbipsIEOLQ%3D%3D | Resistor
R24,R31 | 220R | Resistor_SMD:R_0805_2012Metric | Yageo | RC0805FR-07220RL | 603-RC0805FR-07220RL | https://www.mouser.com/catalog/specsheets/YAGEO_PYu_RC_Group_51_RoHS_L_12.pdf | https://www.mouser.com/ProductDetail/YAGEO/RC0805FR-07220RL?qs=KCkj9j0IqmXa4o%252BHKR6RGw%3D%3D | Resistor
R25-R28,R32 | 47k | Resistor_SMD:R_0805_2012Metric | Yageo | RC0805FR-0747KL | 603-RC0805FR-0747KL | https://www.mouser.com/datasheet/2/447/PYu_RC_Group_51_RoHS_L_11-1984063.pdf | https://www.mouser.com/ProductDetail/YAGEO/RC0805FR-0747KL?qs=sfaR5EV1ye7DERH7OnC2Gg%3D%3D | Resistor
R29 | 10R | Resistor_SMD:R_0805_2012Metric | Yageo | RC0805FR-0710RL | 603-RC0805FR-0710RL | https://www.mouser.com/catalog/specsheets/YAGEO_PYu_RC_Group_51_RoHS_L_12.pdf | https://www.mouser.com/ProductDetail/YAGEO/RC0805FR-0710RL?qs=8Y8p%252BasKcI5T5bn0nqNRsw%3D%3D | Resistor
R30 | 270R | Resistor_SMD:R_0805_2012Metric | Yageo | RC0805FR-07270RL | 603-RC0805FR-07270RL | https://www.mouser.com/catalog/specsheets/YAGEO_PYu_RC_Group_51_RoHS_L_12.pdf | https://www.mouser.com/ProductDetail/YAGEO/RC0805FR-07270RL?qs=fRxXYNj8ftH0PxeHhRcbcA%3D%3D | Resistor
R34 | 100k | Resistor_SMD:R_0805_2012Metric | Yageo | RC0805FR-07100KL | 603-RC0805FR-07100KL | https://www.mouser.com/catalog/specsheets/YAGEO_PYu_RC_Group_51_RoHS_L_12.pdf | https://www.mouser.com/ProductDetail/YAGEO/RC0805FR-07100KL?qs=8Y8p%252BasKcI7rEWn6FcVdAA%3D%3D | Resistor
R35 | 100k 1% | Resistor_SMD:R_0805_2012Metric | Yageo | RC0805FR-07100KL | 603-RC0805FR-07100KL | https://www.mouser.com/catalog/specsheets/YAGEO_PYu_RC_Group_51_RoHS_L_12.pdf | https://www.mouser.com/ProductDetail/YAGEO/RC0805FR-07100KL?qs=8Y8p%252BasKcI7rEWn6FcVdAA%3D%3D | Resistor
R36 | 49.9R 1% | Resistor_SMD:R_0805_2012Metric | Yageo | RC0805FR-0749R9L | 603-RC0805FR-0749R9L | https://www.mouser.com/datasheet/2/447/PYu_RC_Group_51_RoHS_L_11-1984063.pdf | https://www.mouser.com/ProductDetail/YAGEO/RC0805FR-0749R9L?qs=VLOqbHBAO5fOTWOXSZvQ2A%3D%3D | Resistor
R37 | 13.7k 1% | Resistor_SMD:R_0805_2012Metric | Yageo | RC0805FR-0713K7L | 603-RC0805FR-0713K7L | https://www.mouser.com/datasheet/2/447/PYu_RC_Group_51_RoHS_L_11-1984063.pdf | https://www.mouser.com/ProductDetail/YAGEO/RC0805FR-0713K7L?qs=fRxXYNj8ftG7GeT1zL0GIw%3D%3D | Resistor
R38 | 13.3K 1% | Resistor_SMD:R_0805_2012Metric | Yageo | RC0805FR-0713K3L | 603-RC0805FR-0713K3L | https://www.mouser.com/datasheet/2/447/PYu_RC_Group_51_RoHS_L_11-1984063.pdf | https://www.mouser.com/ProductDetail/YAGEO/RC0805FR-0713K3L?qs=7bY8808IzHqrbhVfypq6iw%3D%3D | Resistor
RV1,RV3,RV5,RV6 | 10k log | Potentiometer_THT:Potentiometer_Alpha_RD901F-40-00D_Single_Vertical_CircularHoles | Alpha | RD901F-40-15F-B10K-00DL1 | 311-1940F-15F-B10K | ~ | https://www.mouser.com/ProductDetail/Alpha-Taiwan/RD901F-40-15F-B10K-00DL1?qs=1mbolxNpo8eEwO1hUJUOSQ%3D%3D | Potentiometer
RV2,RV4,RV7,RV8 | 10k | Potentiometer_THT:Potentiometer_Bourns_3296W_Vertical | Alpha | RD901F-40-15F-B10K-00DL1 | 311-1940F-15F-B10K | ~ | https://www.mouser.com/ProductDetail/Alpha-Taiwan/RD901F-40-15F-B10K-00DL1?qs=1mbolxNpo8eEwO1hUJUOSQ%3D%3D | Multi-Turn Trim-potentiometer
SW1 | Power | Connector_JST:JST_VH_B2P-VH_1x02_P3.96mm_Vertical | JST | B4P-VH(LF)(SN) | 306-B4P-VHLFSN | ~ | https://www.mouser.com/ProductDetail/JST-Commercial/B4P-VHLFSN?qs=QpmGXVUTftH3CaZ6tE19SA%3D%3D | Single Pole Single Throw (SPST) switch
U1,U2 | THAT1646 | Package_SO:SOIC-8_3.9x4.9mm_P1.27mm | THAT Corporation | 1646S08-U | 887-1646S08-U | https://www.mouser.com/datasheet/3/4/1/THAT_1606-1646_Datasheet.pdf | https://www.mouser.com/ProductDetail/THAT/1646S08-U?qs=7hHJOukDioSBWO8%252B4y5TTQ%3D%3D | THAT1646 balanced line driver, transformer-like, SOIC-8
U3,U6 | OPA1656ID | Package_SO:SOIC-8_3.9x4.9mm_P1.27mm | Texas Instruments | OPA1656IDR | 595-OPA1656IDR | https://www.ti.com/lit/ds/symlink/opa1656.pdf | https://www.mouser.com/ProductDetail/Texas-Instruments/OPA1656IDR | Dual Ultra-Low-Noise, Low-Distortion, FET-Input, Burr-Brown Audio Operational Amplifiers, SOIC-8
U4,U5 | THAT1246 | Package_SO:SOIC-8_3.9x4.9mm_P1.27mm | THAT Corporation | 1246S08-U | 887-1246S08-U | https://www.mouser.com/datasheet/3/4/1/THAT_1240_Series_Datasheet.pdf | https://www.mouser.com/ProductDetail/THAT/1246S08-U?qs=9Udfh7QmL4sXNHyZVY%252BVng%3D%3D | THAT1246 balanced line receiver, unity gain, SOIC-8
U7 | LM2903 | Package_SO:SOIC-8_3.9x4.9mm_P1.27mm | Texas Instruments | LM2903DR | 595-LM2903DR | http://www.ti.com/lit/ds/symlink/lm393.pdf | https://www.mouser.com/ProductDetail/Texas-Instruments/LM2903DR?qs=6aLkNDRfRUZTZwd6enMTiA%3D%3D | Low-Power, Low-Offset Voltage, Dual Comparators, DIP-8/SOIC-8/SOP-8/TSSOP-8/VSSOP-8
U8 | H11L1 | Package_DIP:SMDIP-6_W7.62mm | Onsemi | H11L1SM | 512-H11L1SM | https://www.onsemi.com/pub/Collateral/H11L3M-D.PDF | https://www.mouser.com/ProductDetail/onsemi/H11L1SM?qs=9h%252BT%2FFFCxR8rbqOmNiGmNQ%3D%3D | Schmitt Trigger Output Optocoupler, High Speed, DIP-6, 1.6mA turn on threshold
U9 | Daisy_Seed | daisy-studio:DAISY_SEED_SMT |  | Daisy Seed | (not on Mouser - buy from electro-smith.com) | https://static1.squarespace.com/static/58d03fdc1b10e3bf442567b8/t/6227e6236f02fb68d1577146/1646781988478/Daisy_Seed_datasheet_v1.0.3.pdf | https://daisy.audio/hardware/Seed/ | Daisy is an embedded platform for music.
U10 | TPS54302 | Package_TO_SOT_SMD:SOT-23-6 | Texas Instruments | TPS54302DDCR | 595-TPS54302DDCR | http://www.ti.com/lit/ds/symlink/tps54302.pdf | https://www.mouser.com/ProductDetail/Texas-Instruments/TPS54302DDCR?qs=zEmsApcVOkUXM7UP0GSO2g%3D%3D | 3A, 4.5 to 28V Input, EMI Friendly integrated switch synchronous step-down regulator, pulse-skipping, SOT-23-6

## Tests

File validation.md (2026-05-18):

# Rev 2 Build & Validation

5 boards on order with full BOM. Build the **first board incrementally**
— populate one subsystem, validate, then move on. Catches PCB issues
(shorts, missing nets, footprint mismatches) before each new section's
parts are at risk. Once Board 1 passes through Stage 4, the remaining
four can be built straight through using the proven sequence.

For circuit operation, see [README.md → Circuit Function](README.md#circuit-function).

## Pre-build sanity

Before reflow / hand-soldering anything:

- [ ] **All five PCBs visually inspected.** Look for fab defects on the
  power section's high-current traces and the BJT clamp ground pours.
- [ ] **H11L1SM footprint matches the populated package.** Datasheet
  pad pitch / size / land length vs. the actual PCB pads. Footprint
  was wrong in Rev 1 and is the highest-confidence fab-side risk.
- [ ] **RS3-1212D pin 3 (CTRL) routed to nothing.** Datasheet forbids
  a low state on this pin; ERC catches the schematic via the
  no-connect flag, but the PCB is the final truth.

## Stage 1 — Power

Goal: all three rails (+5 V, ±12 V) up and clean before any signal-path
silicon is at risk.

### Populate:

- Barrel jack, DMP3056L reverse-polarity FET, SMBJ15CA input TVS,
  100 µF / 25 V bulk on +12V_RAW. Leave SW1 unjumpered initially —
  see 1.2; we're not stocking the JST switch header for this run, so
  SW1 will be wire-bridged after the open-state safety checks.
- TPS54302 + L3 (10 µH) + input MLCC (10 µF X7R 1206) + output caps
  (2× 22 µF / 25 V X7R 1206) + feedback divider + bootstrap cap.
- RS3-1212D + L1, L2 ferrites + post-ferrite bulk caps.
- SMAJ5.0A TVS on +5 V near the Seed footprint.

(JP1 ships pre-bridged from fab — no soldering required to keep
AGND/DGND/CHASSIS tied. See 1.1 for the optional cut-and-restore
isolation check.)

### Preload:

Before first power-up, install dummy loads across the rail breakout
header so each regulator has something to drive — confirms rails
come up under load and surfaces shorts/runaway without putting
downstream silicon at risk:

- **+12VA → AGND**: ~480 Ω, 1 W (≈ 25 mA).
- **−12VA → AGND**: ~480 Ω, 1 W (≈ 25 mA).
- **+5V → DGND**: ~100 Ω, 0.5 W (≈ 50 mA) — gives the TPS54302
  enough load to leave discontinuous-conduction mode for a clean
  ripple measurement; the Seed isn't fitted yet.

Leave these in place for the full Stage 1 power-up sequence — the
RS3-1212D should never see a no-load condition.

### Verify:

All Stage 1 power-up steps use a **bench-top PSU with current
limiting** in place of a wall-wart. Suggested starting limit: 300 mA
at 12 V — comfortably above the expected ~100–200 mA stage-1 draw
(dummy loads + DC/DC quiescent + buck efficiency loss) and tight
enough to fold back on a short before damage.

- [x] **1.1 Ground continuity (power off).** With JP1 bridged
  (default), DMM continuity from AGND through to each chassis
  mounting hole and to the ground shell of every Neutrik combo
  jack. Catches missing CHASSIS bonds and unstitched ground pours
  before any rail comes up.
    - *Optional isolation check (one board only):* cut JP1, confirm
      AGND/DGND no longer reads continuous to CHASSIS while the
      chassis-to-Neutrik-shell continuity remains. Re-bridge JP1
      with solder before continuing.
- [ ] **1.2 SW1-open safety pass (board still powered down).** With
  SW1 unjumpered, set PSU to 12 V / 300 mA limit, leads connected to
  the barrel jack with correct polarity. DMM on +12V_RAW — should
  stay at 0 V, PSU current ≈ 0. Reverse the PSU leads, repeat —
  again 0 V at +12V_RAW, no current. This proves SW1 isolates the
  rest of the board and that nothing bypasses it. Then **bridge
  SW1** with a short wire link soldered across its two pads (the
  panel-switch JST hardware isn't stocked for this build).
- [x] **1.3 +12V_RAW present.** PSU at 12 V, correct polarity, ramp
  from 0 V watching current. DMM on +12V_RAW downstream of the bulk
  cap reaches 11.7–11.9 V (small Vds drop across DMP3056L). Steady-
  state PSU current matches the preload + quiescent budget; nothing
  unexpected. **FAILED** ground not connected (issue #13, Rev 2c fix)
- [ ] **1.4 Reverse-polarity blocks (FET).** Power down, reverse the
  PSU leads, ramp back up. DMP3056L blocks; +12V_RAW stays at 0 V,
  PSU current limited only by leakage (≪ 1 mA). Power down, restore
  polarity, confirm rails recover. **FAILED** Reverse S and D on mosfet
  (issue #14, Rev 2c fix)
- [ ] **1.5 +5 V rail.** DMM on +5 V should read 5.05–5.15 V (FB
  divider 100 k / 13.3 k → 0.6 V × 8.52). AC-coupled scope at the
  same node — ripple well under 50 mV pp at the 500 kHz switching
  frequency. **REVISIT** after everything is fitted.
- [ ] **1.6 ±12 V rails (under preload).** DMM at the +12VA / −12VA
  test points: ±11.76 to ±12.24 V (RS3-1212D ±2%). Scope ripple at
  the same nodes after the ferrites — target < 10 mVpp in the audio
  band. The Preload resistors are the load throughout — **do not
  power the RS3-1212D unloaded**, no-load operation is the failure
  mode we're avoiding.

## Stage 2 — Daisy Seed + MIDI

### Populate:

- Daisy Seed module (**Rev 7 — required for Stage 3.4's PCM3060
  noise test**).
- H11L1SM optoisolator.
- MIDI passives: 220 Ω × 2, 1N4148W, 270 Ω, 33 Ω × 2, 33 Ω, 10 Ω,
  100 nF decouple.
- 3× SDS-50J DIN-5 jacks.
- Micro SD socket.

### Verify:

- [x] **2.1 Seed boots.** Power up. Boot LED on; USB enumerate when
  plugged into a host (DFU / serial device).
- [ ] **2.2 +3V3D from Seed.** DMM at the +3V3D pin on the GPIO
  breakout header.
- [x] **2.3 MIDI THRU passthrough.** External MIDI source (synth or
  USB-MIDI interface) into DIN-5 IN, monitor DIN-5 THRU with an
  external MIDI sink. Send a stream of note-ons; THRU should emit
  the same messages, byte-for-byte, with no Seed firmware involved
  — this exercises the H11L1SM forward path + 33 Ω THRU buffer
  resistors only.
- [x] **2.4 MIDI IN + OUT (digital thru on the Seed).** Load a Seed
  program that echoes every received MIDI byte straight back out
  (RX → TX, a software MIDI thru). External source → DIN-5 IN; sink
  on DIN-5 OUT. Notes sent in should reappear at OUT, exercising
  the full IN-side optoisolation path *and* the OUT-side driver in
  a single loop.
    - Firmware: `firmware/projects/test-midi/`.
- [ ] **2.5 SD card.** Mount + read a card from a test program. **NOT RUN** I'm not in the mood to solder that thing :P

## Stage 3 — Audio output stage

Lower clamp risk than the input — build it first so the codec
spectral check (3.4) runs without depending on input-side silicon.

### Populate:

- OPA1656 (output sheet) + R_in (2.2 kΩ) + R_fb_fixed (15 kΩ) +
  R_fb_trim (10 kΩ Bourns 3296W-1-103) + C_fb (100 pF C0G).
- OPA1656 supply decoupling (100 nF + 1 nF per rail).
- THAT1646 + datasheet decoupling.
- 4× SM4004 per channel (phantom protection at XLR pins).
- 2× SMBJ15CA bidirectional TVS on ±12 V → AGND near the RS3-1212D.
- 2× Neutrik NCJ6FA-H-0 output combo jacks.
- Daughterboard header (main-PCB side — IDC or stack-mount, your
  build mode).

### Calibrate:

**Preferred method — loopback THD analyzer.** The
`firmware/projects/thd-meter` build + `thd-meter.html` Web Serial UI in
**Loopback mode** is the gold-standard trim aid here, far more sensitive
than scope p-p readings. The harmonic table shows H2..H9 in dB below the
fundamental; a clean output stage leaves H4..H9 sitting in the codec
noise floor (~−115 dB and below). The instant the output stage (or
input clamp graze) begins to distort, the **broadband H4..H9 fanout
lifts off the noise floor by 10–30 dB** while the scalar THD number
barely changes. That fanout is the most sensitive single indicator we
have of "clean ceiling crossed" — visible long before THD or scope
shape moves. See F9 below for the method's full story.

- [x] **3.1 Output gain trim, channel L (RV2).**
    1. Set the L output level pot fully clockwise on the
       daughterboard.
    2. Flash `thd-meter`, open `thd-meter.html`, set Mode = Loopback,
       Channel = L (capture), Drive = 1.0 (digital full scale), Window
       = Coherent. Connect L XLR OUT to L XLR IN with a known-good
       cable.
    3. Trim **RV2** until the harmonic table shows H4..H9 dropping
       into the noise floor (≤ −115 dB below fundamental). Around the
       transition you'll see a 0.1 dB rotation pop H4..H9 up 15–25 dB
       — back off the trim until they re-merge with the floor, then
       give yourself a small additional CCW margin (~0.5 dB at the
       codec input level) so component-tolerance drift can't drift
       the chain back into the graze.
    4. Note the codec input level at the locked trim (typically
       −4 to −5 dBFS at digital scale 1.0). Calibrated full-scale
       output is now somewhat below +24 dBu — quote the actual figure
       in the calibration sticker.
    5. Lock the trim with nail polish / trim paint.
- [x] **3.2 Output gain trim, channel R (RV4).** Same procedure on R,
  trimming **RV4**. Match L's locked codec input level within
  ~0.1 dB. See F1 and F9 in findings.
  **Done (Board 1, post-F1 R_fb swap, post-F9 procedure update):** both
  channels re-trimmed using the loopback-THD method. Earlier scope-only
  trim landed both channels at the BJT-clamp graze threshold (per F5)
  with R about 0.8 dB hotter than L — produced a clear H4..H9 fanout on
  R at digital full scale. After re-trim, fanout merged into the noise
  floor on both channels.

**Reference designator note:** **RV2 = L feedback trim**, **RV4 = R
feedback trim** (audio_output.kicad_sch). RV2 sits in the top half of
the sheet near `AUDIO_OUT_L`; RV4 in the bottom near `AUDIO_OUT_R`.
Worth a hand-label on the silkscreen — same class of L/R-identification
trap as F8.

### Verify:

- [ ] **3.3 Phantom-power survival (bench-PSU simulated +48 V).**
  Daisy Studio fully powered down throughout this test (no supply
  on the barrel jack). A separate bench PSU plus two resistors
  emulates the phantom feed network of a real preamp.
    1. Build the phantom feed: 2× **6.81 kΩ, ¼ W** resistors, in
       parallel between the bench PSU's positive output and the two
       hot pins (XLR pin 2 + pin 3) of one Daisy Studio output. PSU
       − returns to Daisy Studio AGND or chassis.
    2. Scope on +12 V at the RS3-1212D output / an OPA1656 supply
       pin, DC-coupled.
    3. Set the bench PSU to **48 V, current limit ≈ 50 mA**. If the
       supply caps below 48 V, stack two channels in series; a 30 V
       test exercises the same path but won't push +12 V high enough
       to engage the TVS, so it isn't a complete check.
    4. Ramp from 0 → 48 V watching scope and PSU current. Expected:
       ~5 mA per pin, ~10 mA total into +12 V via the SM4004 forward
       clamps. SMBJ15CA on +12 V → AGND clamps at **16–24 V** — the
       +12 V rail should rise to that band and stop, no runaway
       above.
    5. Power down phantom PSU, swap to the other XLR output, repeat.
    6. Disconnect the phantom rig, restore Daisy Studio power,
       confirm op-amp + THAT1646 still pass signal cleanly (no
       SM4004 / TVS damage).
- [ ] **3.4 Reconstruction-LPF spectral check (Seed Rev 7 only).**
    - 3.4a XLR diff noise floor with C_fb **un**populated, Seed playing
      digital silence.
    - 3.4b Repeat with C_fb = 100 pF populated.
    - 3.4c Compare broadband floor + spectral content above 40 kHz.
      AD2 spectrum analyzer at 1 MS/s sample rate covers this — the
      relative delta in the >40 kHz region is what matters; AD2 self-
      noise is ~40 dB above the codec's audio-band floor so this is
      *not* an audio-band measurement. (For audio-band confirmation
      you'd need an audio-grade interface — see Equipment.)
    - 3.4d **Escalation gate.** If 1-pole @ 80 kHz looks insufficient
      against the codec's actual spectrum → escalate to a 2-pole
      Sallen-Key post-gain-stage (board-revision-scale change). Do
      **not** increase C_fb — it kills the audio top octave. Pause
      further population on remaining boards until decided.

## Stage 4 — Audio input stage (highest-risk block)

The BJT clamp + OPA1656 + ±1.565 V reference is sim-validated only.
This stage is where Rev 2's novel circuitry gets bench-confirmed.

### Populate:

- THAT1246 + datasheet decoupling.
- OPA1656 (input sheet) + R_in (10 kΩ) + R_fb (12 kΩ) + supply
  decoupling.
- R_out (3.3 kΩ).
- BJT clamp per channel: 2N3906 PNP + 2N3904 NPN.
- Reference dividers per channel: 10 kΩ + 1.5 kΩ each rail + 47 µF
  X7R 1206 holding caps to AGND.
- C_aa (1 nF C0G) at the Seed input pin.
- LM2903 dual comparator + 1 kΩ LED limit + decoupling.
- 2× Neutrik NCJ6FA-H-0 input combo jacks.

### Signal-level reference (sim)

Source: `sim/input/measure.asc` — 1 kHz sine, `.tran` with `.step amp` ×
`.step pk`. All values **V p-p**.

**Per-stage levels** (independent of pot position):

| Input level | Balanced (each leg) | THAT1246 out | OPA1656 out |
|---|---:|---:|---:|
| +4 dBu | 1.74 | 1.74 | 2.08 |
| +18 dBu | 8.70 | 8.70 | 10.45 |
| +24 dBu | 17.36 | 17.36(17.23) | 20.83(20.6/20.72) |

Each leg p-p ≡ differential p-p / 2. THAT1246 has −6 dB ⇒ single-ended
output p-p numerically matches each-leg p-p. OPA1656 fixed gain ×1.2;
stays inside ±11 V rails at +24 dBu — no opamp clip.

**Pot sweep — +4 dBu in** (OPA out = 2.08 V p-p):

| Pot rotation | Wiper | Seed_In | measured without seed |
|---:|---:|---:|---|
| 0% | ~0(0/0) | ~0(0/0) | 0/0 |
| 20% | 0.38 | 0.30 | |
| 50% | 0.91(1.049/1.025) | 0.73(0.485/0.479) | 1.039/1.019 |
| 70% | 1.29 | 1.04 | |
| 100% | 2.08(2.10/2.12) | 1.67(1.046/1.046) | 2.06/2.05 |

**Pot sweep — +18 dBu in** (OPA out = 10.45 V p-p):

| Pot rotation | Wiper | Seed_In | opa out |
|---:|---:|---:|---:|
| 0% | ~0 | ~0 | 10.36 |
| 20% |  1.90 | 1.53 | 10.36 | 
| 50% |  4.54 | 3.64 (2.35/2.27) | 10.36 |
| 70% |  6.27 | 4.63 ⚠ clamp engaging | 10.37 |
| 100% | 10.45 | 4.79 ⚠ clamp asymptote (4.17/4.15) | 10.37 |

**Pot sweep — +24 dBu in** (OPA out = 20.83 V p-p):

| Pot rotation | Wiper | Seed_In |
|---:|---:|---:|
| 0% | ~0 | ~0 |
| 20% | 3.80 | 3.04 ⚠ clamp engaging |
| 50% | 7.96 (9.63/9.48) | 4.73 ⚠ clamp asymptote(4.14/4.12) |
| 70% | 10.78 | 4.80 |
| 100% | 20.83 (20.75/20.62) | 4.92 (4.26/4.24) |

Clamp asymptote at Seed_In is **~4.8–4.9 V p-p** (≈ ±2.45 V peaks)
regardless of how hard the wiper is driven — symmetric ±1.565 V
reference assumed. Per F5 the actual bench reference is asymmetric, so
expect positive peaks to clamp ~9% earlier.

### Verify:

- [ ] **4.1 Reference rails.** DMM at +VCLAMP_L, +VCLAMP_R, −VCLAMP_L,
  −VCLAMP_R. **Note: asymmetric per F5** (clip-threshold pot loading
  the + dividers):
    - −VCLAMP_L/R: **−1.51 to −1.62 V** (nominal −1.565 V, R ±1 % +
      rail ±2 %).
    - +VCLAMP_L/R: **+1.34 to +1.45 V** (nominal +1.40 V, R ±1 % +
      pot ±5 % end-to-end + rail ±2 %).
    - Confirm per-channel independence — driving overdrive on one
      channel must not move the other channel's reference.
- [ ] **4.2 Clean-signal gain sweep.** Inject +4 / +14 dBu balanced
  at the THAT1246. Scope the Seed input pin across pot travel.
  Scaling matches the README Performance table — clean at +4 dBu,
  OPA output ~3.3 V peak at +14 dBu, no clamp conduction.
- [ ] **4.3 Pathological overdrive — codec_max.** +24 dBu balanced
  in, input level pot fully clockwise (worst case). Scope the Seed
  input pin: **p-p ≤ 4.8 V** (set by the Seed's input-pin ESD clamp
  diodes — the codec itself is AC-coupled and re-biased to mid-rail
  internally). Sim says **4.49–4.64 V p-p** across tolerance
  corners (assumed symmetric ±1.565 V VCLAMP); want ≥ 100 mV
  margin to 4.8 V p-p. Per F5, the actual clamp is asymmetric —
  expect ~+2.08 V on positive peaks, ~−2.27 V on negative peaks
  (≈ 4.35 V p-p) on the bench.
- [ ] **4.4 Op-amp recovery.** Drop input back to +4 dBu after the
  +24 dBu overdrive — signal returns clean within < 100 µs, no
  latch-up, no rail-stick.
- [ ] **4.5 Reference pumping under overdrive.** During +24 dBu
  overdrive, scope +VCLAMP_* and −VCLAMP_* — should shift < 50 mV
  (sim says 18 mV). This is the BJT clamp's headline behaviour over
  passive diode alternatives.
- [ ] **4.6 Clip-LED threshold trim (RV7 channel L, RV8 channel R —
  see F8 note on swapped sides).** Set the trip point at the actual
  input-clamp engagement, using the loopback-THD method as the
  reference, *not* an arbitrary mid-travel position:
    1. Mode = Loopback, Channel = side under trim, Drive = 1.0,
       Window = Coherent. Output level pot full CW.
    2. Slowly raise the output level pot (or equivalently the
       feedback trim) until the **H4..H9 fanout** just begins to lift
       off the noise floor — this is the BJT clamp graze threshold
       per F5.
    3. Adjust the clip-LED trim (RV7/RV8) so the LED transitions from
       dark to first visible glow at exactly that signal level.
    4. Verify: back off the output pot slightly → LED returns to dark
       and H4..H9 return to floor. Drive a bit harder → LED brightens
       proportionally and H4..H9 lift further. The LED should fire
       just before the THD analyzer detects audible distortion onset.
    5. Per F5, the +VCLAMP asymmetry means the positive-peak clamp
       engages first; this naturally aligns the LED with the worst-
       side limit, which is the conservative choice.

**Later with more boards:**

- [ ] **4.7 codec_max across boards.** Repeat 4.3 on all five.
  Single-board codec_max is not representative; tolerance corner
  validation needs the population. Want every board ≤ 4.8 V p-p
  with ≥ 100 mV margin.

**Open noise-floor item:**

- [ ] **4.8 Audio-band noise floor.** Input shorted at the XLR.
  Compare to sim's 1.4 µV rms output-noise estimate. Requires an
  audio-grade interface (MOTU M2/M4, RME Babyface, Cosmos APU) —
  AD2's ~1–2 mV RMS self-noise is ~40 dB above the expected floor.
  If only AD2 is available, document the gap rather than reporting
  the AD2 measurement as the board's noise floor.

## Stage 5 — Daughterboard + integration

**Populate (daughterboard fab — separate PCB):**

- 2× 10 kΩ log audio pots (input level, L + R).
- 2× 10 kΩ log audio pots (output level, L + R).
- 2× 10 kΩ trim pots (clip threshold, L + R).
- 2× clip LEDs.
- Mating header (IDC ribbon socket or Samtec stack-mount socket).

**Verify:**

- [ ] **5.1 Pot rotation matches level change.** L and R separately,
  both stages.
- [ ] **5.2 Mute leg works.** CCW = silence, no leakage with full
  upstream signal.
- [ ] **5.3 Clip-threshold trim through the cable.** Behaviour
  matches the bench-trim version from Stage 4.
- [ ] **5.4 End-to-end signal path.** Balanced input → balanced
  output, both channels, levelled to taste.
- [ ] **5.5 Soak / listen test.** Real audio source for 30+ min —
  hum, hiss, intermittents, thermal drift.

## Findings

### F1 — Output gain stage clips at R_fb = 15 kΩ on ±12 V rails

**Symptom (Board 1, Stage 3.1):** With R_fb_fixed = 15 kΩ + 10 kΩ
trim, the trim had to be dialled fully CCW (R_fb_total = 15 kΩ,
gain 6.82×) to get an undistorted output. Any rotation above the
end stop clipped at 0 dBFS.

**Bench measurements:**

- Codec output, single-ended on the codec side of R5/R6, at 0 dBFS
  1 kHz sine (sent via `firmware/projects/calibrate-output/`):
  **3.43 V p-p = 1.213 Vrms = +3.89 dBu**.
- ±12 V rails under signal load: **±12.12 V**, no sag.

**Analysis:** OPA1656 on ±12.12 V swings to ~±11.6 V peak under
the THAT1646 + 10 kΩ pot load — ~8.2 Vrms = **+20.5 dBu SE** =
**+26.5 dBu differential** at the rail limit. At gain 6.82× the
target OPA output is 1.213 × 6.82 = 8.27 Vrms = +20.6 dBu SE,
which is 0.1 dB into clipping. Matches the bench.

The Rev 2 design memo's "+21 to +25.6 dBu peak" headroom estimate
assumed ~1.5 dB more rail clearance than the OPA1656 actually
delivers on ±12 V. The 15 kΩ fixed value was set under that
optimistic ceiling.

**Resolution (Rev 2c — issue #15):** Swap R_fb_fixed (R2, R7) from
15 kΩ to **6.8 kΩ** (5.6 kΩ acceptable as a stock alternate). Keep
the 10 kΩ Bourns trim. New range 6.8–16.8 kΩ → gain 3.09× to 7.64× →
peak differential output +19.7 to +27.6 dBu (OPA clip ceiling
+26.5 dBu).

- **+24 dBu calibration target lands at trim ≈ 44 % rotation** —
  near mid-pot, best resolution per turn and best tolerance margin
  between L and R during 3.2 channel-match.
- Top of trim travel sits ~1.1 dB past OPA clip — provides margin
  for component tolerance and lets the calibration procedure verify
  headroom by dialling up to clip and backing off.
- Minimum gain 3.09× = +19.7 dBu diff does *not* reach the +18 dBu
  consumer level. Acceptable — user can attenuate at the output
  level pot on the daughterboard if a lower nominal is needed.

**Action:** Rev 2b bench mitigation — hand-swap R2/R7 to **10 kΩ**
(closest in-stock value, sufficient to clear the clip ceiling and let
Stage 3 validation proceed). Rev 2c spin ships with 6.8 kΩ default
per the schematic / BOM update. Re-run 3.1 / 3.2 after the swap.

### F2 — GPIO header collides with Seed USB during programming

**Symptom (Board 1):** The GPIO breakout header on the main PCB sits
close enough to the Daisy Seed's USB connector that a USB cable
plugged in for programming/DFU fouls the header (or anything mated
into it). Programming the Seed in-circuit while the daughterboard
ribbon is connected is awkward at best.

**Resolution (Rev 3 — issue #16):** Move the GPIO header further from
the Seed USB cutout so a standard USB-micro plug + boot has clearance.
Assume a right-angle low-profile USB breakout cable on the host side
(specific part TBD) — pick the header position to accommodate it.

**Action:** Defer to Rev 3. No change to Rev 2b / 2c schematic / PCB.

### F3 — H11L1SM optoisolator pads still under-sized

**Symptom (Board 1, pre-build inspection / hand-soldering):** The Rev 2
H11L1SM footprint pads are *just* wide enough to capture the package
leads — soldering is workable but there's almost no land beyond the
lead edges for fillet or for visual inspection. Better than Rev 1
(where the footprint was outright wrong, flagged in pre-build sanity)
but still under IPC-recommended land allowance.

**Resolution (Rev 2c — issue #17):** Extend the pad lengths outward
(away from the package body) so each lead sits on a land with normal
toe/heel fillet allowance per IPC-7351. No change to the pitch or
pad width (which appear to match the package).

**Action:** Rev 2b mitigation — careful hand-soldering on populated
boards; not a blocker. Rev 2c spin ships with corrected footprint.
Pre-build sanity item ("H11L1SM footprint matches the populated
package") to be updated for the new land geometry on Rev 2c.
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

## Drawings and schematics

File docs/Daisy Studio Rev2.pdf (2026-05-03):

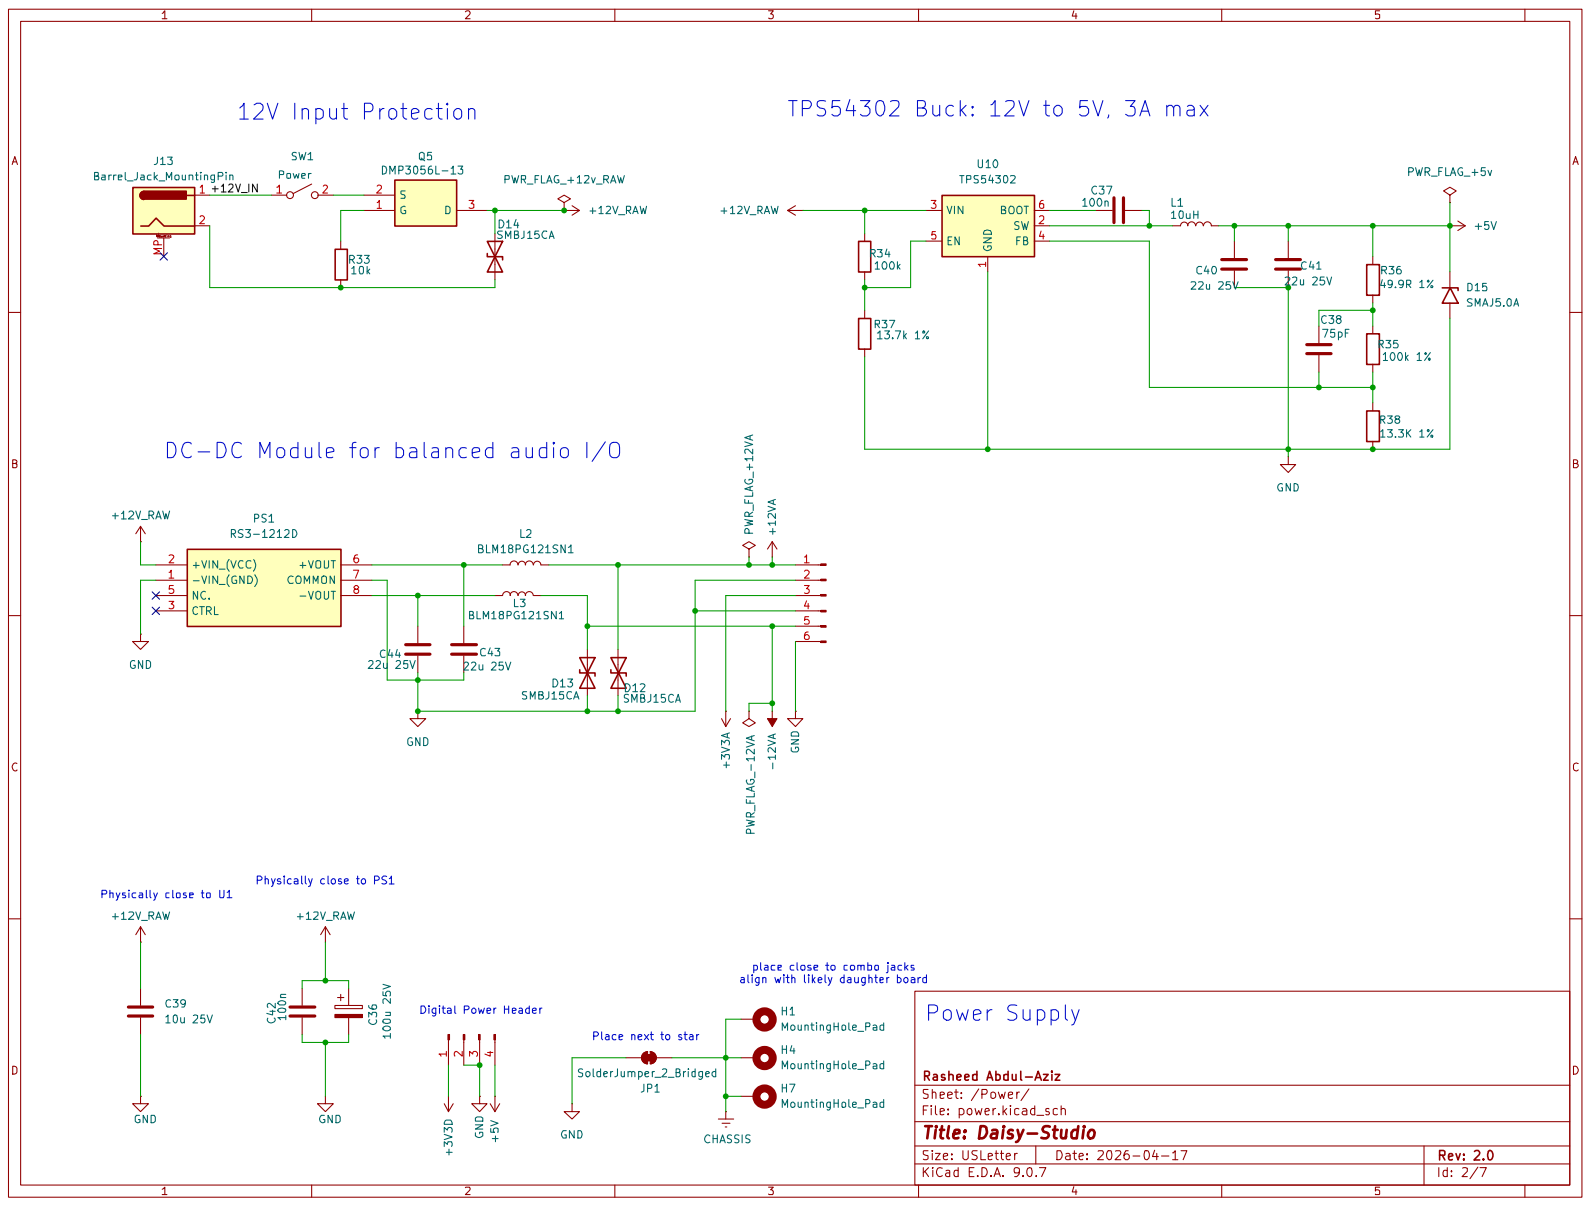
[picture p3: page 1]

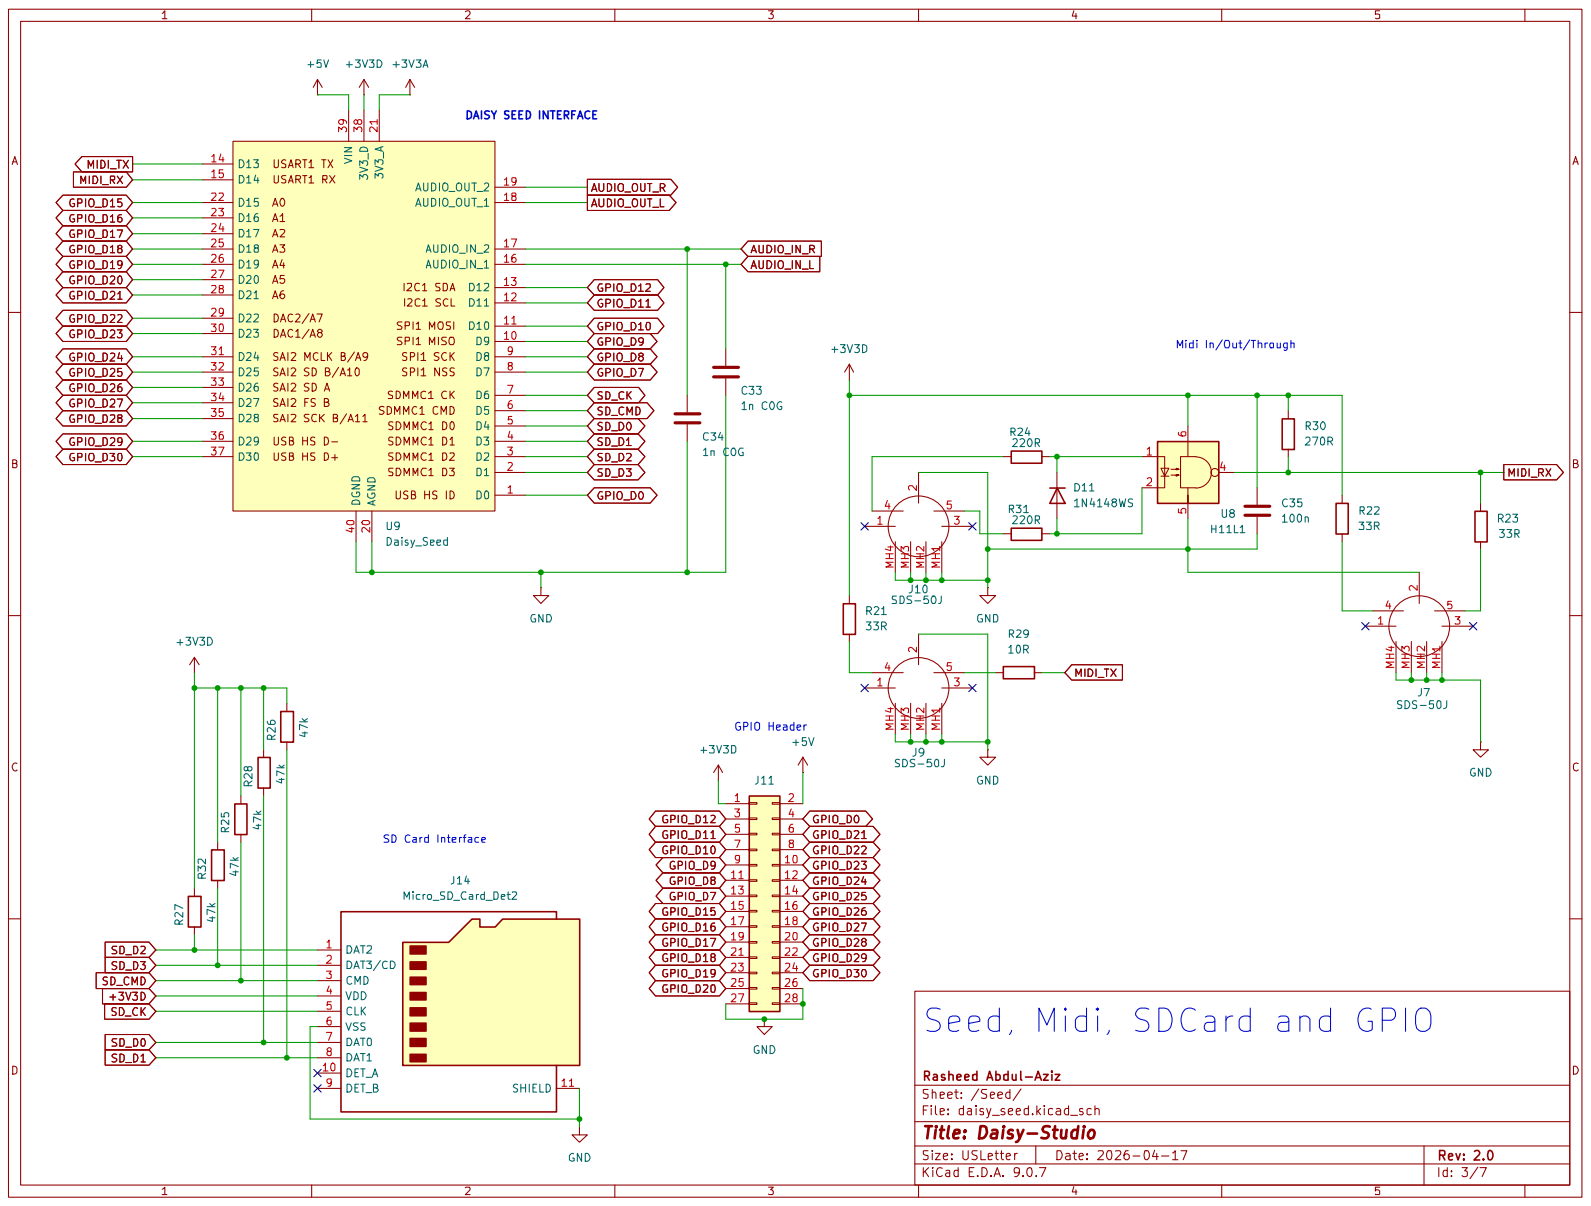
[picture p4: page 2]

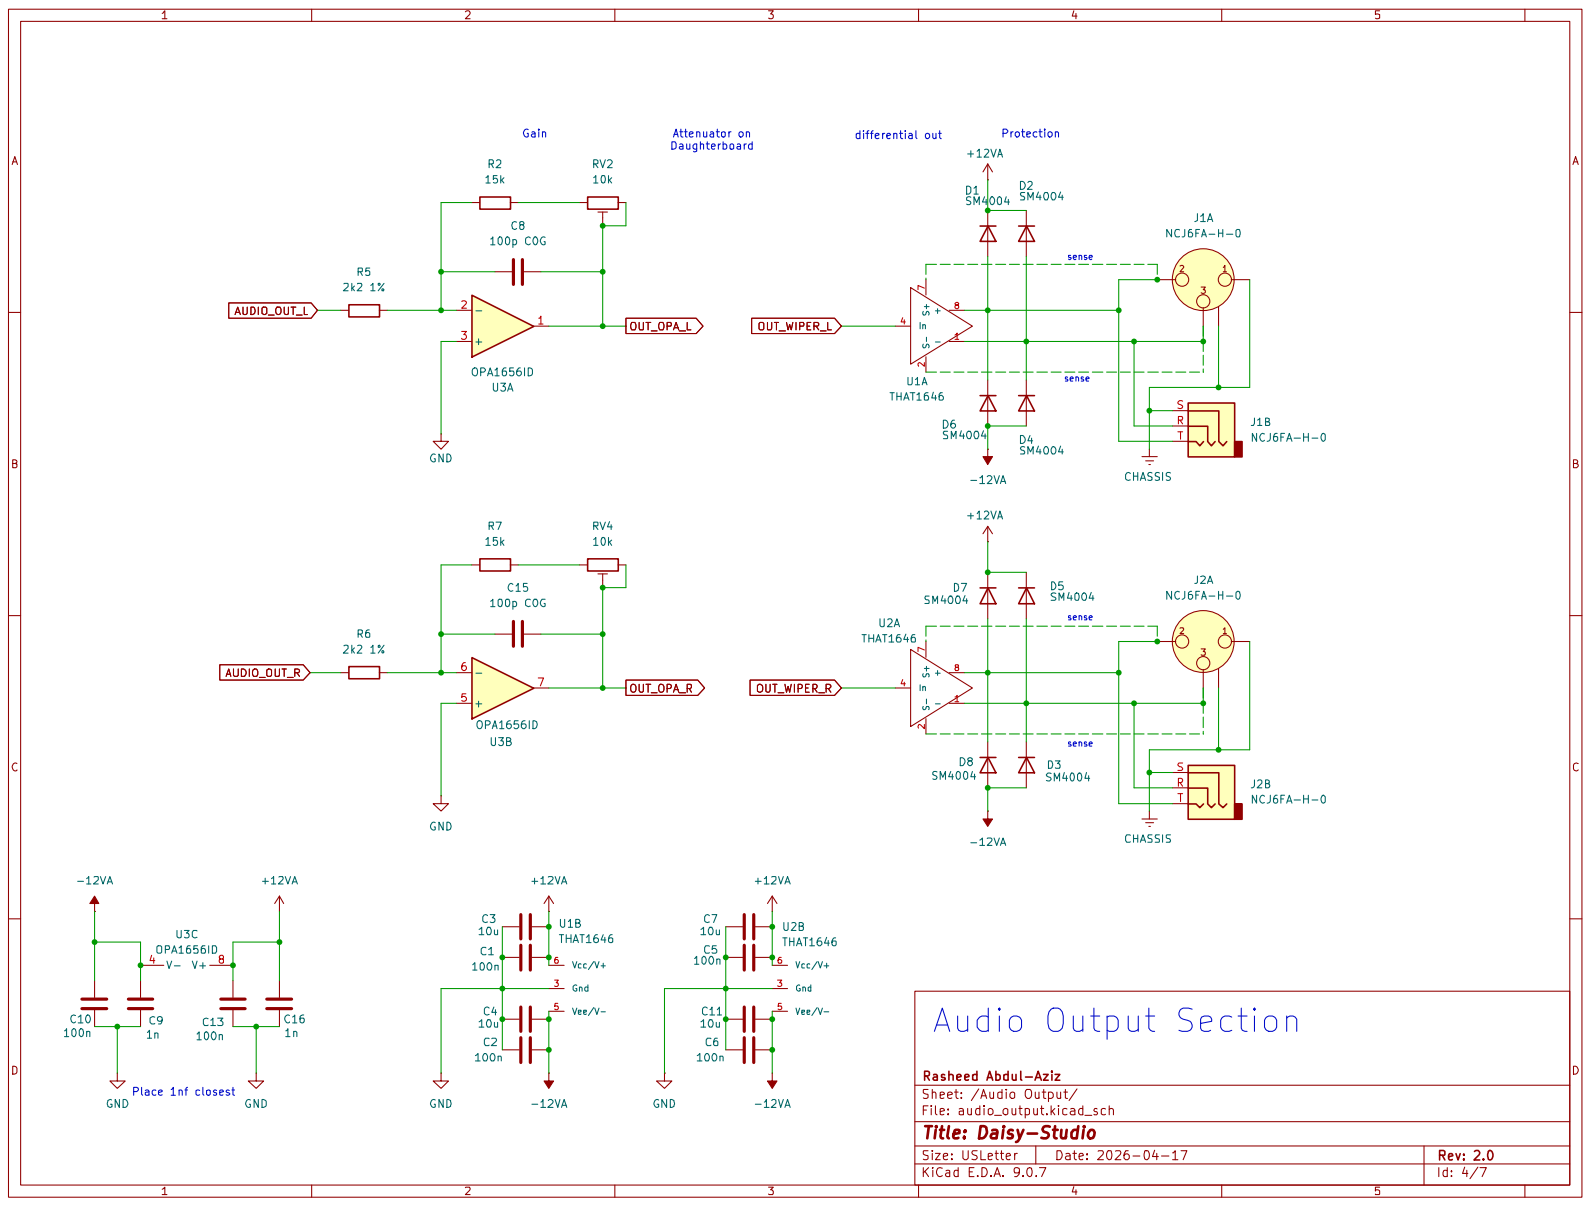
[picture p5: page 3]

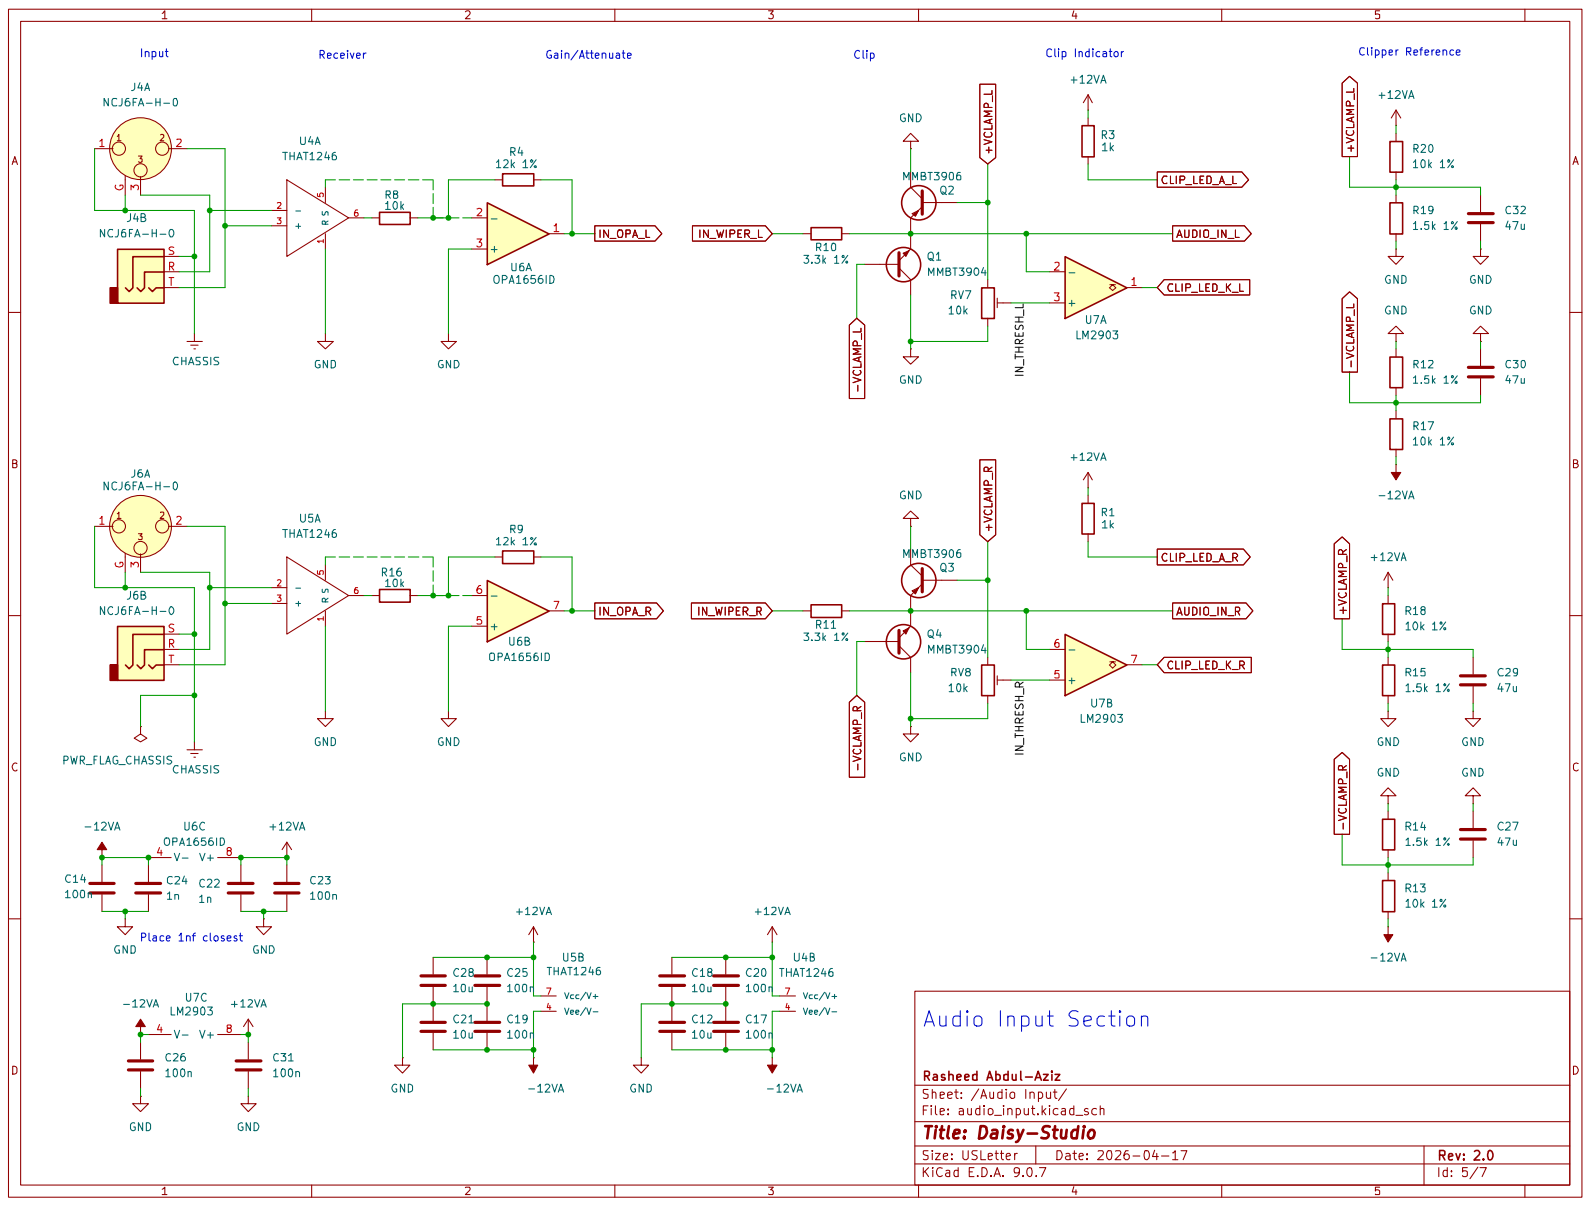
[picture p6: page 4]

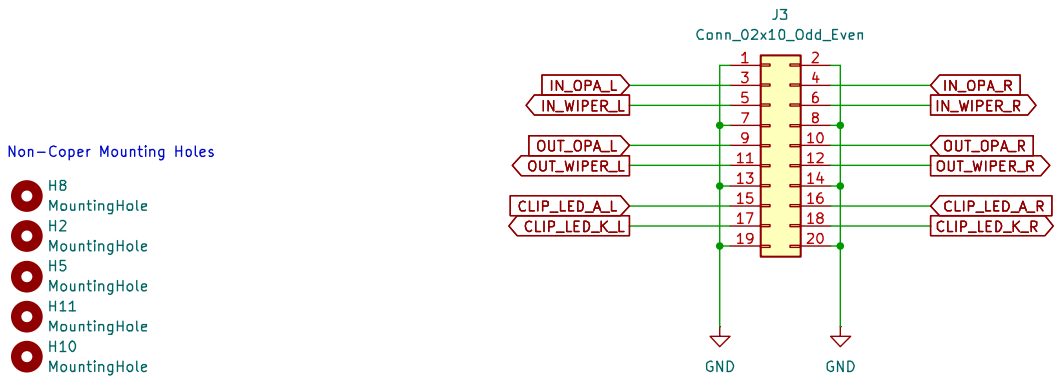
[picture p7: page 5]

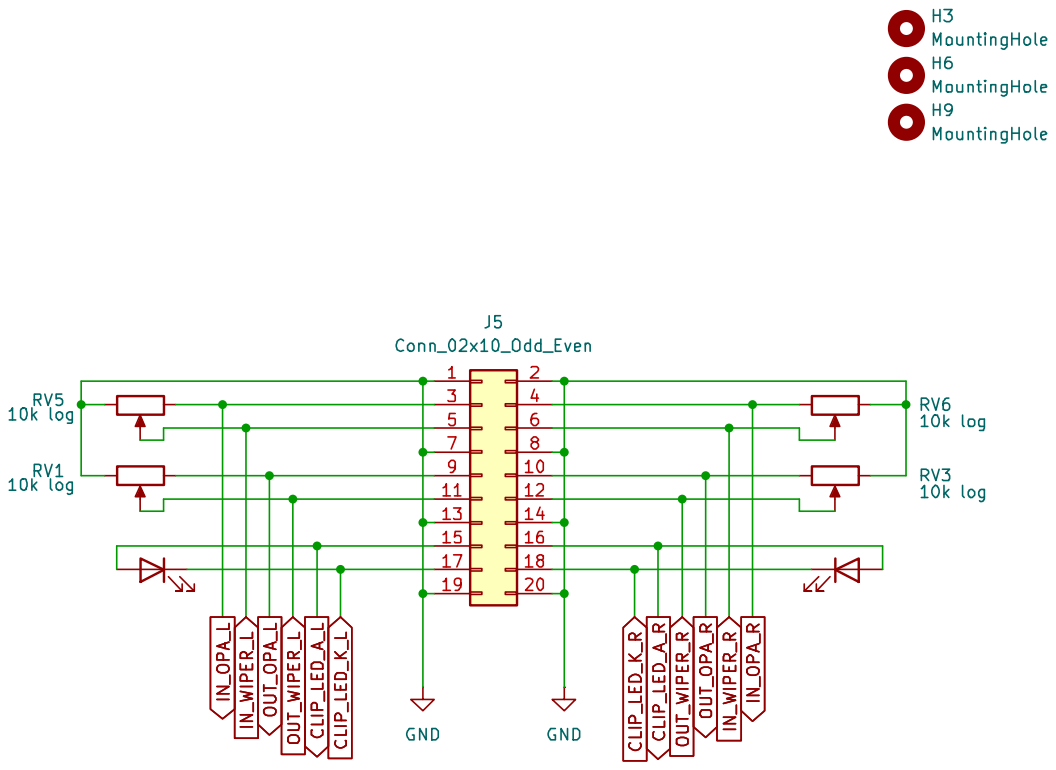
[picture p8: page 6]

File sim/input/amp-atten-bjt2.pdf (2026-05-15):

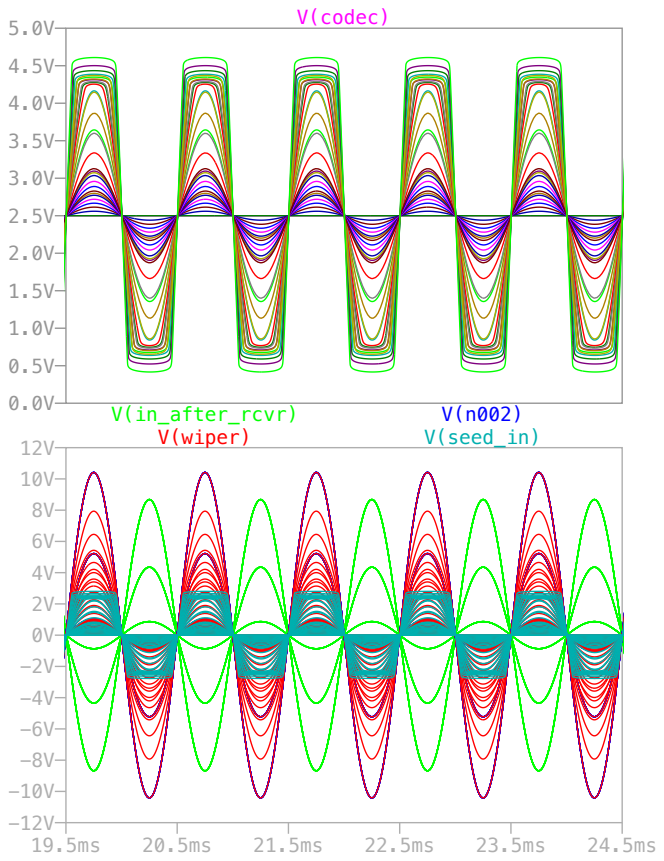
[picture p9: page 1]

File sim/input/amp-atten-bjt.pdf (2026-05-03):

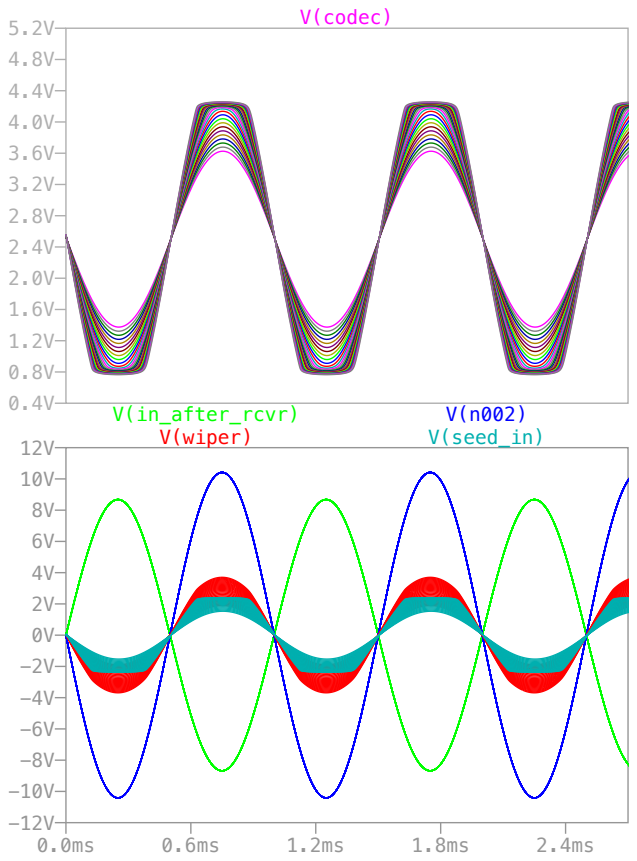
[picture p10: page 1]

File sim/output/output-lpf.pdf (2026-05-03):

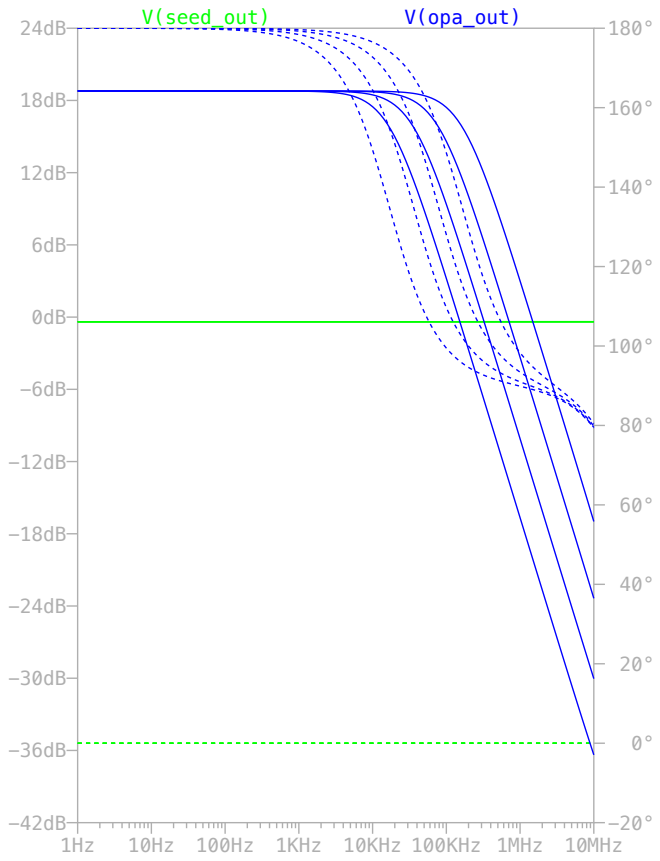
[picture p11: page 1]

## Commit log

2026-04-05 fix lib refs
    [audio.kicad_sch, daisy_seed.kicad_sch]
2026-04-05 update datasheets
    [audio.kicad_sch, daisy-studio.kicad_pcb, daisy_seed.kicad_sch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]
2026-04-12 add placement notes into the schematic
    [audio.kicad_sch, power.kicad_sch]
2026-04-13 dealing with protection circuit changes
    [audio.kicad_sch, bom.csv, daisy-studio.kicad_sch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]
2026-04-13 deleted 3.55mm input jacks
    [audio.kicad_sch]
2026-04-13 Long winded description of a trim mixer and clip circuit
    [bom-old.csv]
2026-04-14 driving the design to as much headroom as i can get
    [thd-plus4db.csv]
2026-04-14 capture current workable gain stage
2026-04-14 making plans to tighten the clamp zone
2026-04-15 current implementation via feedback clamp. very tight on codex_max
    [thd-plus4db.csv]
2026-04-15 change from sharper-diode to sharper-bjt
    [sharper-diode.csv]
2026-04-17 update prototype:
2026-04-18 update clip indicator on prototype and in main design
2026-04-18 audio input for rev 2 laid out in schematic
    [audio.kicad_sch, audio_outpu.kicad_sch, daisy-studio.kicad_sch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]
2026-04-19 output design update
    [audio.kicad_sch, audio_outpu.kicad_sch, daisy_seed.kicad_sch]
2026-04-20 refining input
    [amp-atten-bjt-knee.csv]
2026-04-20 validate latest spec
    [amp-atten-bjt-full.csv, amp-atten-bjt-knee.csv]
2026-04-20 reworking with new tolerances
    [amp-atten-bjt-tolerance.csv]
2026-04-20 final input design i think
    [amp-atten-bjt-knee-E.csv]
2026-04-20 filtering output
    [output-lpf.csv]
2026-04-24 some cleanups
    [bom-rev1.csv]
2026-04-24 design work for power section
2026-04-25 record stock levels/remainders
    [bom-rev1.csv]
2026-04-26 Cleanup and review of input pt 1
    [audio.kicad_sch, audio_outpu.kicad_sch, daisy-studio.kicad_sch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]
2026-04-26 fix some footprints
    [audio.kicad_sch, audio_outpu.kicad_sch, daisy-studio.kicad_sch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]
2026-04-26 introduce daughter board
    [audio.kicad_sch, audio_outpu.kicad_sch, daisy-studio.kicad_sch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]
2026-04-26 starting on output
    [audio.kicad_sch, audio_outpu.kicad_sch, daisy-studio.kicad_sch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]
2026-04-27 daughterboard added
    [audio.kicad_sch, audio_outpu.kicad_sch, daisy-studio.kicad_sch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]
2026-04-27 WIP trying to fix symbols and finish daughterboard
    [audio.kicad_sch, audio_outpu.kicad_sch]
2026-04-27 WIP adding values
    [audio.kicad_sch, daisy-studio.kicad_sch]
2026-04-27 All the testpoints
    [audio.kicad_sch, audio_outpu.kicad_sch, daisy_seed.kicad_sch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]
2026-04-27 fix filenames
    [audio_input.kicad_sch, audio_output.kicad_sch, daisy-studio.kicad_sch]
2026-04-27 TVS fix
    [audio_output.kicad_sch, daughter.kicad_sch, power.kicad_sch]
2026-04-27 working on output
    [audio_output.kicad_sch, daisy_seed.kicad_sch, daughter.kicad_sch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]
2026-04-27 fixed connectors
    [audio_output.kicad_sch, daughter.kicad_sch, misc.kicad_sch]
2026-04-27 changed pacge nums
    [audio_input.kicad_sch, daisy-studio.kicad_sch]
2026-04-27 fix seed schematic
    [audio_input.kicad_sch, audio_output.kicad_sch, daisy_seed.kicad_sch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]
2026-04-27 footprints fixed
    [audio_input.kicad_sch, audio_output.kicad_sch, daughter.kicad_sch]
2026-04-27 fix up power values
    [power.kicad_sch]
2026-04-27 reannotate, fix cap footprints
    [audio_input.kicad_sch, power.kicad_sch]
2026-04-27 add power switch
    [power.kicad_sch]
2026-04-27 add protection to 5v
    [power.kicad_sch]
2026-04-27 update power - still not happy
    [audio_output.kicad_sch, power.kicad_sch]
2026-04-27 change docs to use RS3-1212D
    [audio_input.kicad_sch, audio_output.kicad_sch, daisy_seed.kicad_sch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]
2026-04-27 clean up symbols and values
    [power.kicad_sch]
2026-04-27 Fix R6
    [power.kicad_sch]
2026-04-28 lots of pcb work
    [audio_input.kicad_sch, daisy-studio.kicad_pcb]
2026-04-29 clean up some power cap issues
    [audio_input.kicad_sch, daisy-studio.kicad_pcb, daisy_seed.kicad_sch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]
2026-04-29 final layout
    [audio_input.kicad_sch, audio_output.kicad_sch, bom.csv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]
2026-04-29 clean up vias
    [daisy-studio.kicad_pcb]
2026-04-30 Rev 2 Fab sent
    [daisy-studio.kicad_pcb]
2026-04-30 fix header
    [bom.csv, daisy_seed.kicad_sch]
2026-04-30 update bom with links and validated data
    [bom.csv]
2026-05-03 added 3d models
    [audio_input.kicad_sch, audio_output.kicad_sch, bom-rev1.csv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]
2026-05-03 charcoal not white neutrik
    [daisy-studio.kicad_pcb]
2026-05-03 Power section fixes
2026-05-06 fix j8 value
    [power.kicad_sch]
2026-05-07 update scanner, fix 2.0 version on pcb
    [daisy-studio.kicad_pcb]
2026-05-07 Rev2b - fix LEDs
    [daisy-studio.kicad_pcb]
2026-05-08 first blush at 3d viewer
    [daisy-studio.kicad_pcb]
2026-05-08 fix neutrik position in 3d
    [daisy-studio.kicad_pcb]
2026-05-08 board edge fix
2026-05-08 fix board height
2026-05-08 start up showing whole board
2026-05-08 Stop tracking 3D viewer build artifacts
    These are regenerated by `make build` from the source files (kicad_pcb,
    docs.md, etc.) and were bloating the repo.
2026-05-08 Add make deploy target — push local build to gh-pages
    Bypasses CI entirely. Local `make build` is the source of truth; the
    new scripts/deploy.sh syncs docs/3d-viewer/ into a temporary worktree
    on the gh-pages branch and force-pushes. GitHub Pages serves from there.
    Removes the seven CI-experiment commits (.github/workflows/, _libs/,
    bake_models.py, bake_sds50j.py, SDS-50J_baked.glb) that came after
    64f9b50 — they aren't needed once we're not building on the runner.
2026-05-13 more observations and fixes to the validation flow
2026-05-26 fix ground #13
    [daisy-studio.kicad_pcb, power.kicad_sch]
2026-05-26 Fix reverse polarity mosfet
    closes #14
    [daisy-studio.kicad_pcb, daughter.kicad_sch, power.kicad_sch]
2026-05-26 r_fb_fixed changed to 6.8k
    closes #15
    [audio_output.kicad_sch, daisy-studio.kicad_pcb]
2026-05-26 make optocoupler pads longer for hand soldering
    fixes: 17
    [daisy-studio.kicad_pcb]
2026-06-08 Split daughter board (#27)
    * split finished up without finalizing the daughterboard
    This is rather incomplete, as I have a whole new plan for the PCBs.
    But at least the main board is right. Use flying leads to affix gain/atten controls
    [audio_input.kicad_sch, audio_output.kicad_sch, bom.csv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]
2026-06-09 Tackle pre expermintal work (#28)
    **Pre-experimental fixes — #18 #19 #20 #21**
    Four correctness fixes on the input clamp circuit before the next experimental round:
    - **Clamp transistor footprint** (#18): Switched Q_clamp from TO-92 (2N3906) to SOT-23 (PZT3906) — updates datasheet, description, sim pin mapping (B/E/C), and footprint filter in the PCB.
    - **Threshold trimmer value** (#19): Raised RV_threshold from 10k → 100k so the wiper no longer drags down the clamp reference positive rail.
    - **Sense line placement notes** (#20): Added schematic annotations directing R8 and R16 close to U6b to keep the sense lines short; corrected junction positions in the output topology section.
    -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
    [audio_input.kicad_sch, audio_output.kicad_sch, main-board.kicad_pcb]
